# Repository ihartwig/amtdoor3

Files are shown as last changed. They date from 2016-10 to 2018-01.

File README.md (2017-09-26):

AMT Door 3
==========

This repository houses hardware for the 3rd generation smart lock at Ace Monster Toys in Berkeley, CA. The hardware and software in this repo plus the PoEPi Hat make a single-cable solution for network connected locks.

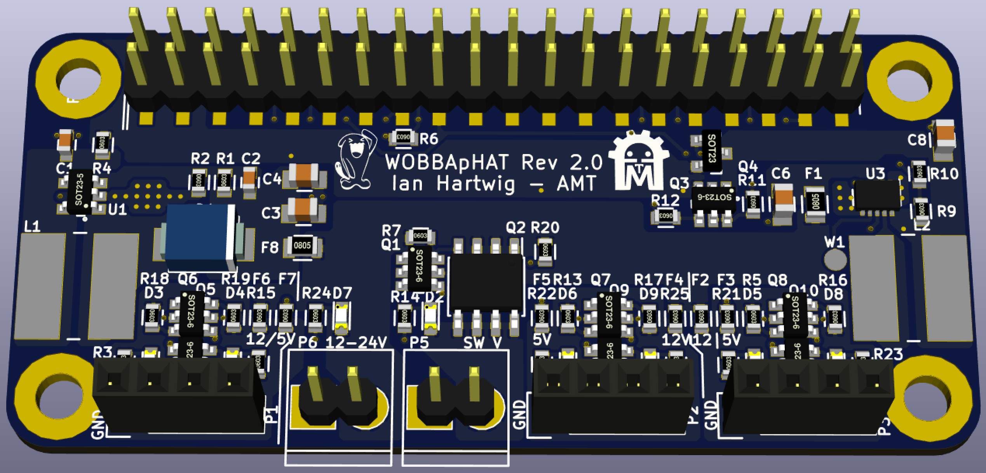
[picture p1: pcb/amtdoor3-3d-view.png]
AMT Door 3 Breakout 3D render


## Features

* Wide Operation Buck Boost and Automation pHat (WOBBApHAT)
  * RPi Zero-sized pHAT
  * bi-directional level shifting for RFID Reader I/O (UART), PWM, and switch inputs (GPIO)
  * 12-24V strike power from on-board boost or aux input
  * (optionally) 5V RPi power from 12-24V source
  * order at http://dirtypcbs.com/store/designer/details/9832/5763/wobbaphat-for-amtdoor3

## Development Structure

* **docs**: Documentation used in designs.
* **pcb**: WOBBApHAT board to connect RPi Zero with RFID Reader and door strike.

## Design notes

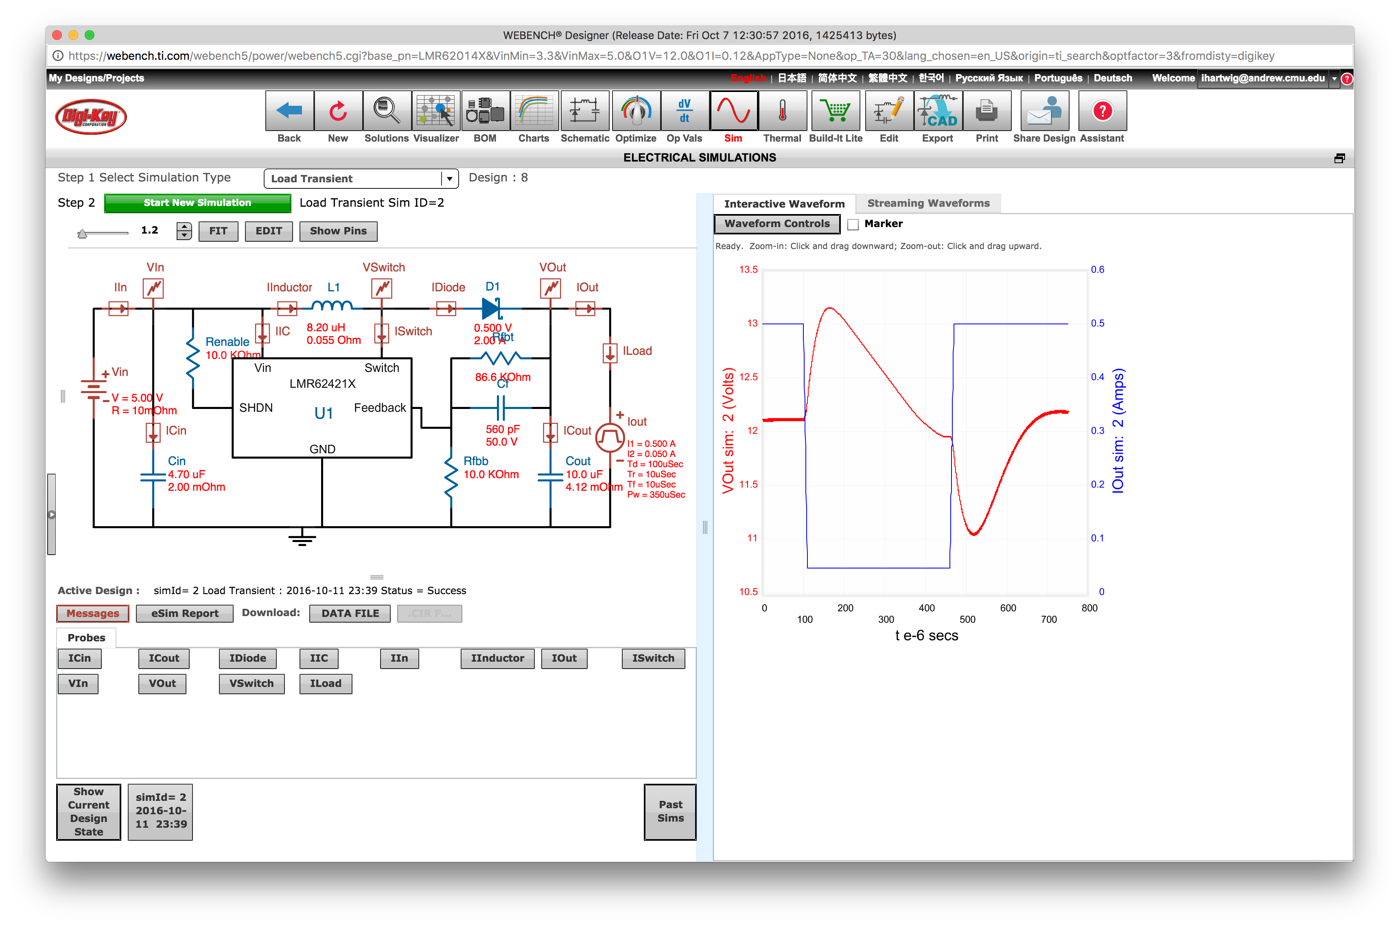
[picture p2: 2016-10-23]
docs/Screen Shot 2016-10-11 at 11.40.16 PM.png

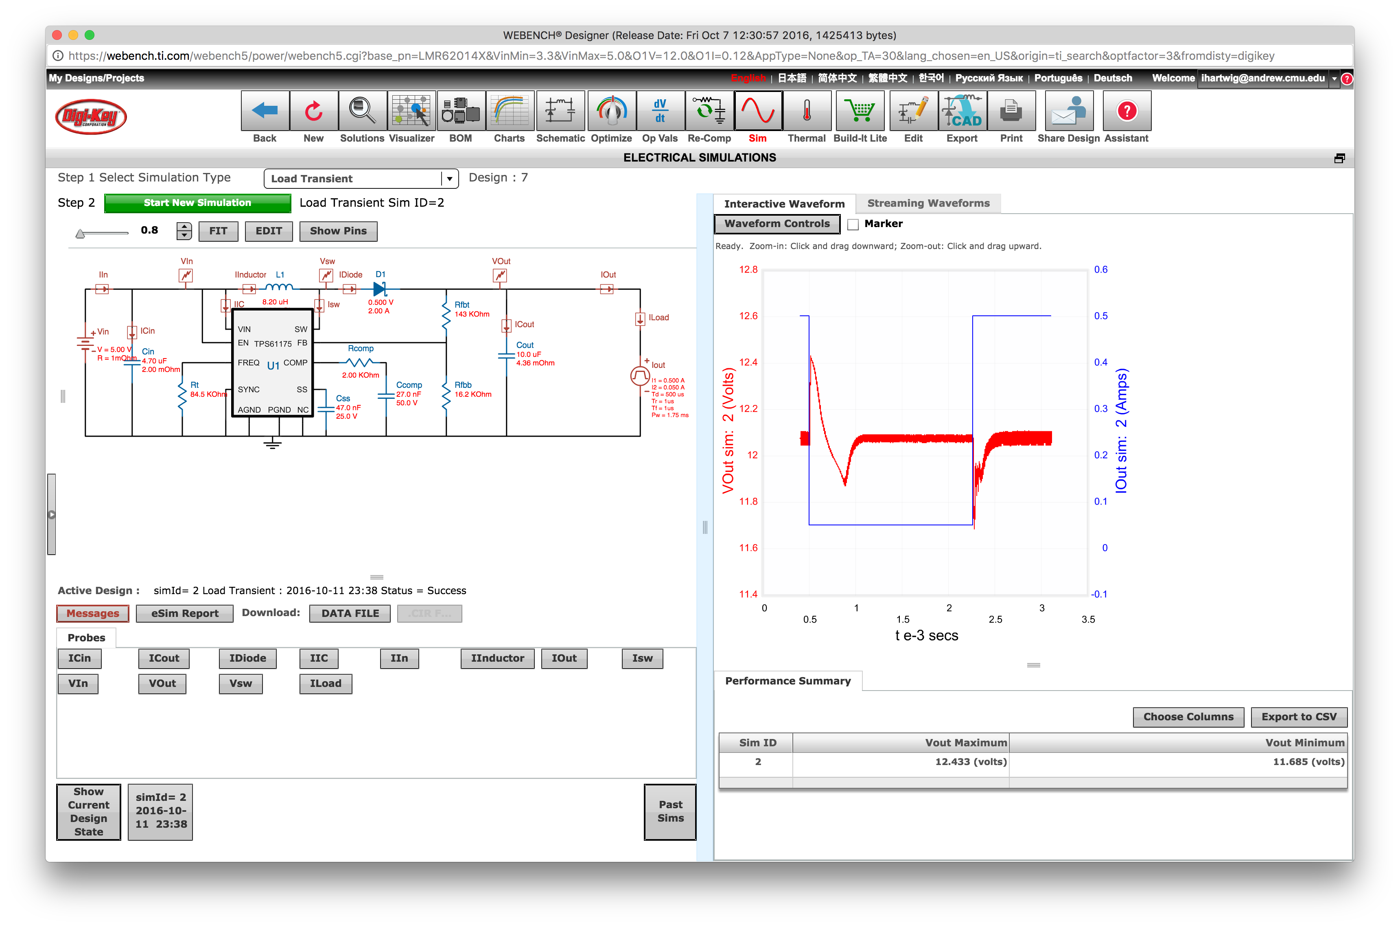
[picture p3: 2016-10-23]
docs/Screen Shot 2016-10-11 at 11.38.27 PM.png

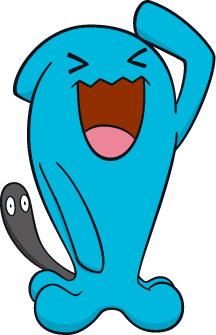
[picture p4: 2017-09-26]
pcb/wobbuffet.png

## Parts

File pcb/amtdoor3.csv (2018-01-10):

Component | Description | Part | References | Value | Footprint | Quantity Per PCB | Datasheet | Type | Digikey Part No | Mfg | Mfg Part No | Pop | Alt Mfg | Alt Mfg Part No
1 | Unpolarized capacitor | C_Small | C2 | 15pF | C_0603 | 1 |  | SMT
2 | Unpolarized capacitor | C_Small | C1 | 1uF | C_0603 | 1 |  | SMT
3 | Unpolarized capacitor | C_Small | C3 C4 C6 | 2.2uF 50V | C_0805 | 3 |  | SMT
4 | Unpolarized capacitor | C_Small | C8 | 22uF 10V | C_0805 | 1 |  | SMT
5 | Schottky diode, small symbol | D_Schottky_Small | D1 | 15V 1A | SMB_Standard | 1 |  | SMT | VS-10BQ015-M3/5BTGICT-ND | Vishay Semiconductor | VS-10BQ015-M3/5BT
6 |  | Led_Small | D2 D3 D4 D5 D6 D7 D8 D9 | LED Green | LED_0603 | 8 |  | SMT | 160-1183-1-ND | Lite-On | LTST-C190GKT
7 |  | F_Small | F1 | 250mA | R_0805 | 1 |  |  |  |  |  | DNP
8 |  | F_Small | F8 | 500mA | R_0805 | 1 |  |  |  |  |  | DNP
9 |  | F_Small | F2 F3 F4 F5 F6 F7 | F_Small | R_0603 | 6 |  |  |  |  |  | DNP
10 |  | AMT-LOGO | G3 | AMT-LOGO | amt-logo-fcu | 1
11 |  | AMT-LOGO | G4 | AMT-LOGO | amt-logo-fsilk-lg | 1
12 |  | WOBBAPHAT-LOGO | G1 | WOBBAPHAT-LOGO | wobbaphat-logo-fcu | 1
13 |  | WOBBAPHAT-LOGO | G2 | WOBBAPHAT-LOGO | wobbaphat-logo-fsilk-lg | 1
14 |  | hole-metalized-no4 | H1 H2 H3 H4 | hole-metalized-no4 | hole-m3 | 4 |  | nostuff
15 |  | INDUCTOR_SMALL | L2 | 10uH | Choke_SMD_Wuerth-WE-PD2-Typ-L | 1 |  | SMT | 587-2081-1-ND | Taiyo Yuden | NR6045T100M
16 |  | INDUCTOR_SMALL | L1 | 4.7uH | Choke_SMD_Wuerth-WE-PD2-Typ-L | 1 |  | SMT | 587-2100-1-ND | Taiyo Yuden | NR6028T4R7M
17 |  | CONN_01X02 | P5 P6 | CONN_01X02 | Pin_Header_Straight_1x02_Pitch3.5mm | 2 |  | TH | ED2740-ND | On Shore Technology, Inc. | OSTTE020104
18 |  | CONN_01X04 | P1 P2 P3 | CONN_01X04 | Socket_Strip_Straight_1x04 | 3 |  | TH
19 |  | CONN_02X20 | P4 | dnp-REF-182665-01 | Pin_Header_Straight_TH-SMT-NoPaste_2x20 | 1 |  |  |  |  |  | DNP
20 |  | DMMT3906_Dual_PNP | Q3 | DMMT3906_Dual_PNP | SOT-23-6 | 1 |  | SMT | DMMT3906-7-FDICT-ND | Diodes Inc | DMMT3906-7-F
21 | Transistor Dual N-MOSFET (DMN63D8LDW, 2N7002DW) | Q_NMOS_DUAL | Q1 Q5 Q6 Q7 Q8 Q9 Q10 | Q_NMOS_DUAL | SOT-23-6 | 7 |  | SMT | DMN5L06DMKDICT-ND | Diodes Inc | DMN5L06DMK-7
22 | Transistor P-MOSFET with substrate diode (general) | Q_PMOS_GSD | Q4 | Q_PMOS_GSD | SOT-23 | 1 |  | SMT | DMP3099L-7DICT-ND | Diodes Inc | DMP3099L-7
23 | Transistor P-MOSFET High Power (IRF9393, DMP3056) | Q_PMOS_HP | Q2 | Q_PMOS_HP | SOIC-8_3.9x4.9mm_Pitch1.27mm | 1 |  | SMT | DMG4435SSS-13DICT-ND | Diodes Inc | DMG4435SSS-13 |  | Diodes Inc | DMP3085LSS-13
24 | Resistor, small symbol | R_Small | R4 | 0 | R_0603 | 1 |  |  |  |  |  | DNP
25 | Resistor, small symbol | R_Small | R5 R6 R7 R11 R13 R16 R17 R18 R19 R20 | 10k | R_0603 | 10 |  | SMT
26 | Resistor, small symbol | R_Small | R10 | 150k | R_0603 | 1 |  | SMT
27 | Resistor, small symbol | R_Small | R3 R15 R21 R22 R23 R25 | 1k | R_0603 | 6 |  | SMT
28 | Resistor, small symbol | R_Small | R14 R24 | 2.2k | R_0603 | 2 |  | SMT
29 | Resistor, small symbol | R_Small | R1 | 432k | R_0603 | 1 |  | SMT
30 | Resistor, small symbol | R_Small | R12 | 47k | R_0603 | 1 |  | SMT
31 | Resistor, small symbol | R_Small | R2 | 49.9k | R_0603 | 1 |  | SMT
32 | Resistor, small symbol | R_Small | R9 | 787k | R_0603 | 1 |  | SMT
33 | Boost Switching Regulator IC Positive Adjustable 2.5V 1 Output 1.4A | SC4503-TSOT-23 | U1 | SC4503-TSOT-23 | SOT-23-5 | 1 |  | SMT | SC4503TSKCT-ND | Semtech Corporation | SC4503TSKTRT |  | Texas Instruments | LMR62421XMF/NOPB
34 | 28-V, 0.5-A Step-Down Converter With Sleep Mode | TPS62177 | U3 | TPS62175 | DFN-10-1EP_2x3mm_Pitch0.5mm | 1 |  | SMT | 296-39451-1-ND | Texas Instruments | TPS62175DQCR
35 | point | TEST_1P | W1 | TEST_1P | Measurement_Point_Round-SMD-Pad_Small | 1
Component Groups: | 35
Component Count: | 76
Fitted Components: | 76
Number of PCBs: | 1
Total components: | 76
Schematic Version: | 2.0
Schematic Date: | 2017-09-25
BoM Date: | Thursday, January 04, 2018 'PMt' 11:07:57 PM
Schematic Source: | /Users/ihartwig/repos/amtdoor3/pcb/amtdoor3.sch
KiCad Version: | Eeschema 4.0.7

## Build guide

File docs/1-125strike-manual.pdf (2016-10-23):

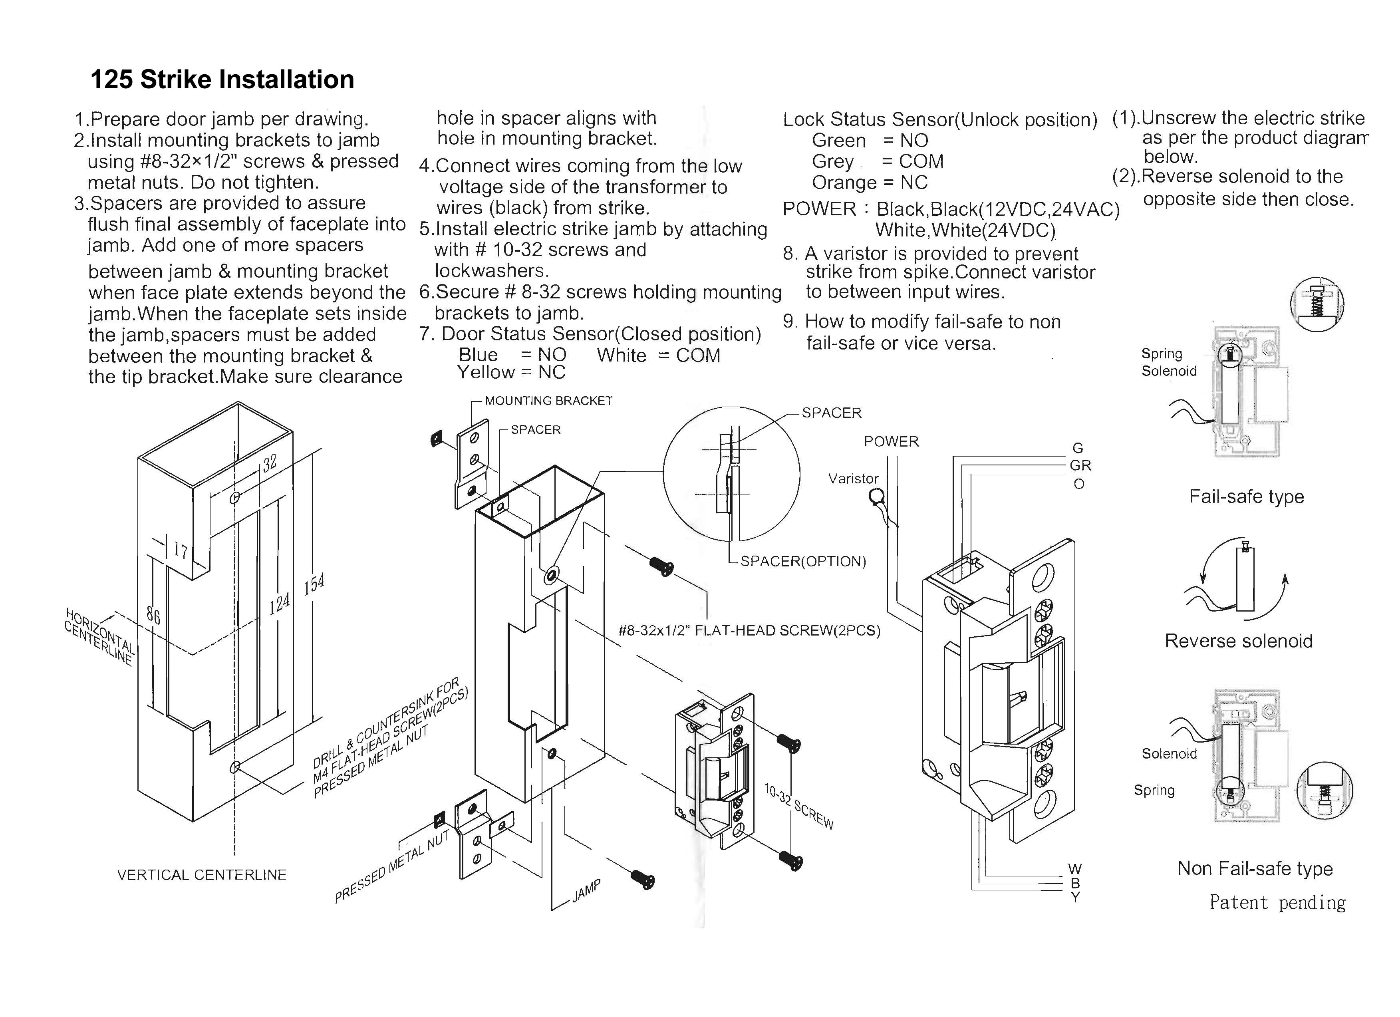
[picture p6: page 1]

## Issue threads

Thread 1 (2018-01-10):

GPIO indicator LEDs are flipped

ihartwig, 2018-01-10:
GPIO indicator LEDs are next to their pair's pin instead of their own because the dual FET package have G and S on the same side.

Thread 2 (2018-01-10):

24V signals are only safe to 20V

ihartwig, 2018-01-10:
All the 24V signals touch the gate of a dual FET somewhere, and it looks like those parts only come with a Vgs max of +-20V. Add resistors or find a dual FET that doesn't seem to exist.

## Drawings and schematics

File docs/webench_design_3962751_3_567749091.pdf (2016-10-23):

## WEBENCH ® Design Report

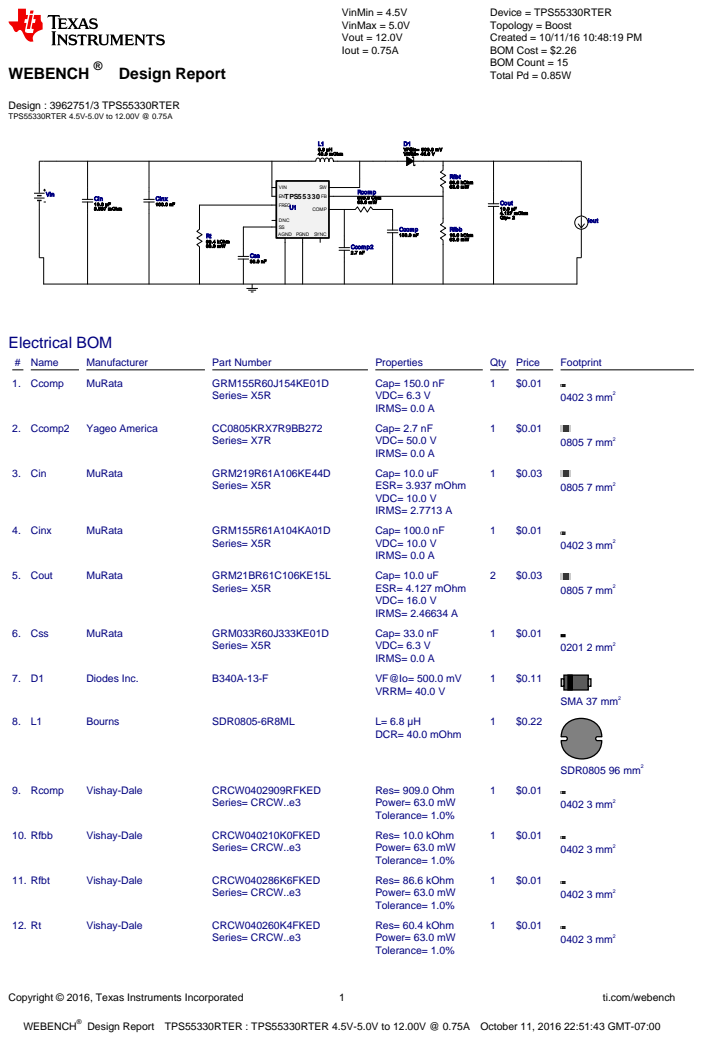
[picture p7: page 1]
Copyright © 2016, Texas Instruments Incorporated; ti.com/webench; WEBENCH®; Design : 3962751/3 TPS55330RTER TPS55330RTER 4.5V-5.0V to 12.00V @ 0.75A; VinMin = 4.5V VinMax = 5.0V Vout = 12.0V Iout = 0.75A; Device = TPS55330RTER Topology = Boost Created = 10/11/16 10:48:19 PM BOM Cost = $2.26 BOM Count = 15 Total Pd = 0.85W; Ccomp 150.0 nF; Ccomp2 2.7 nF; Cin 10.0 µF 3.937 mOhm; Cinx; Cout 10.0 µF; 4.127 mOhm Qty= 2; Css 33.0 nF; D1 VF@Io= 500.0 mV VRRM= 40.0 V; L1 6.8 µH 40.0 mOhm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

Design Report TPS55330RTER : TPS55330RTER 4.5V-5.0V to 12.00V @ 0.75A October 11, 2016 22:51:43 GMT-07:00

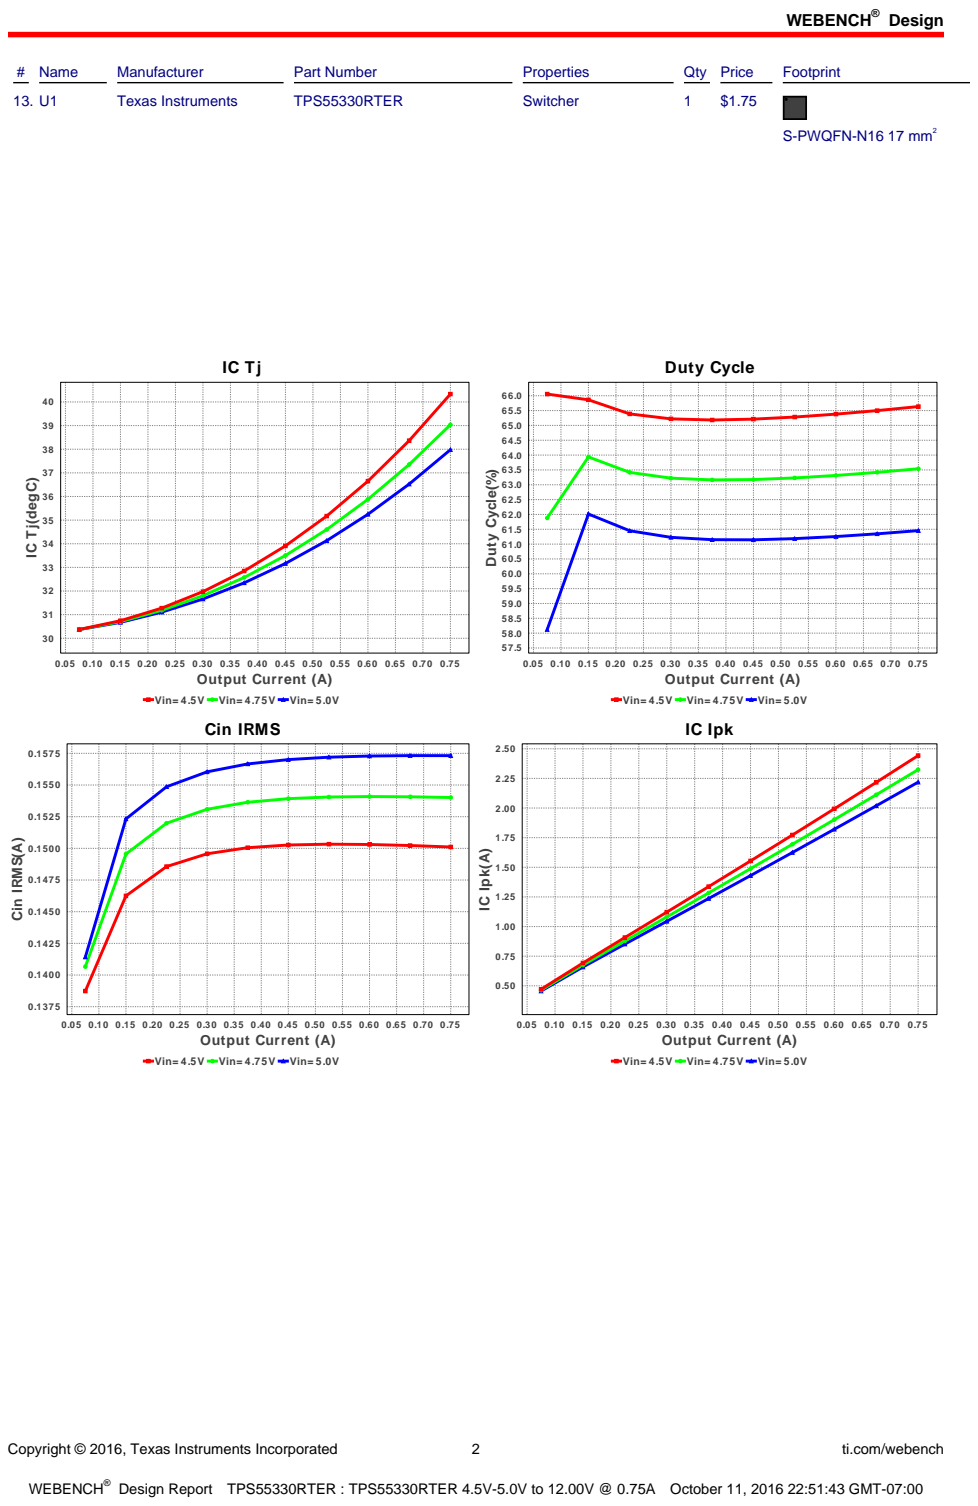
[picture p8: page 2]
Design; Copyright © 2016, Texas Instruments Incorporated; ti.com/webench; # Name; Manufacturer; Part Number; Properties; Qty Price; Footprint; Texas Instruments; TPS55330RTER; Switcher; S-PWQFN-N16 17 mm²; 0.05 0.10 0.15 0.20 0.25 0.30 0.35 0.40 0.45 0.50 0.55 0.60 0.65 0.70 0.75 Output Current (A); Duty Cycle; Duty Cycle(%); Cin IRMS(A); IC Ipk; IC Ipk(A)

IC Tj(degC)

Vin= 4.5V Vin= 4.75V Vin= 5.0V
Cin IRMS

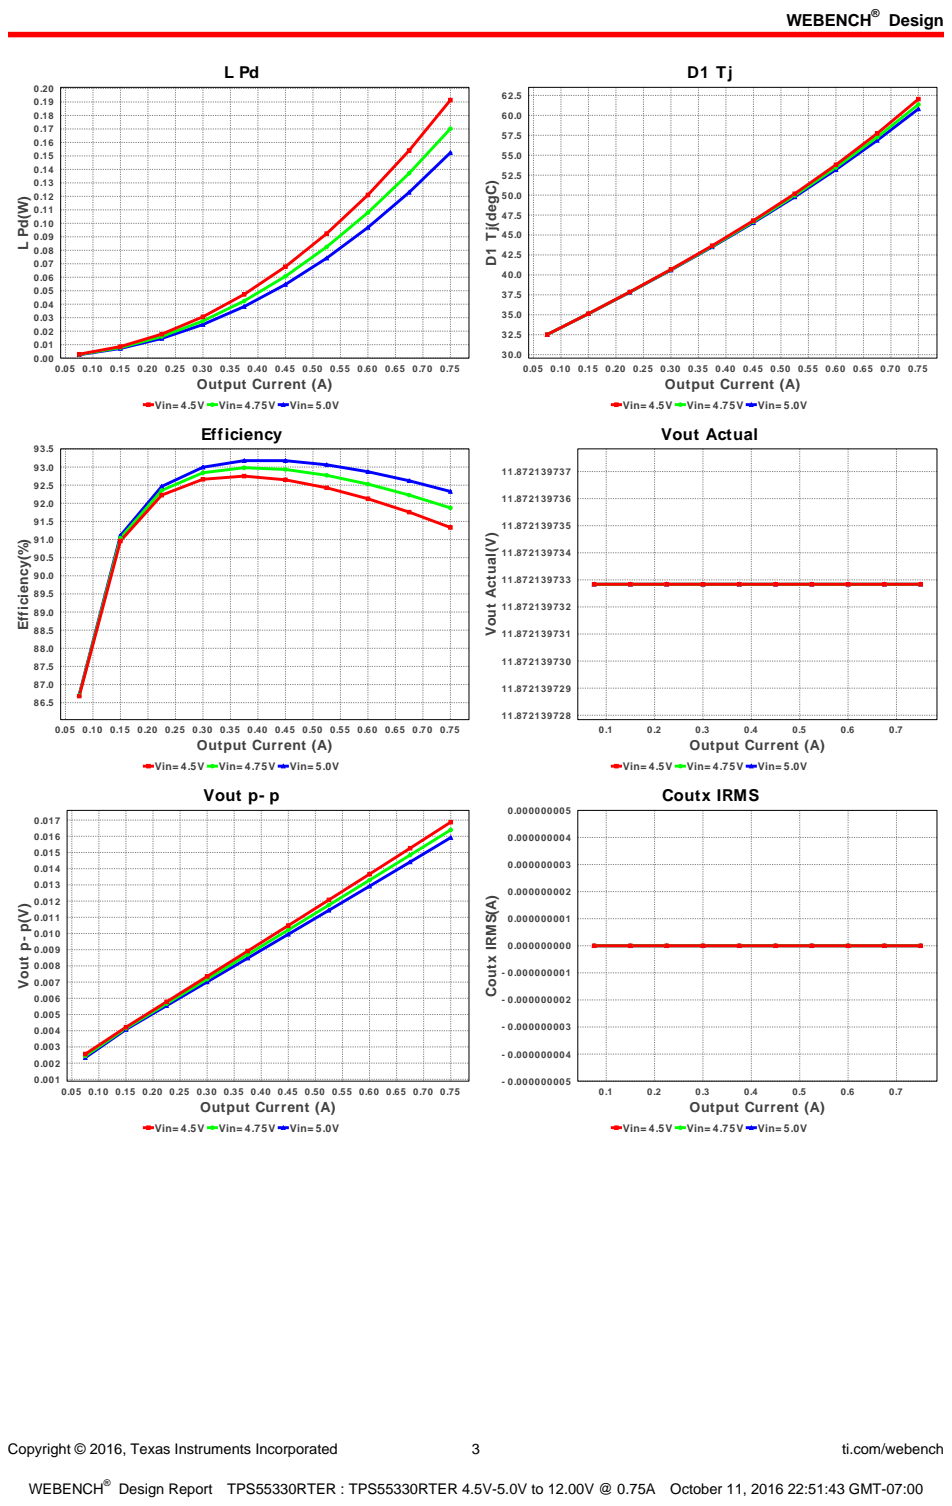
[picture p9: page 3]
Copyright © 2016, Texas Instruments Incorporated; ti.com/webench; 0.05 0.10 0.15 0.20 0.25 0.30 0.35 0.40 0.45 0.50 0.55 0.60 0.65 0.70 0.75 Output Current (A); D1 Tj(degC); Efficiency(%); 0.7 Output Current (A); Vout Actual(V); Vout p- p(V); Coutx IRMS(A)

Vin= 4.5V Vin= 4.75V Vin= 5.0V
Efficiency

Vout Actual

Vout p- p

Coutx IRMS

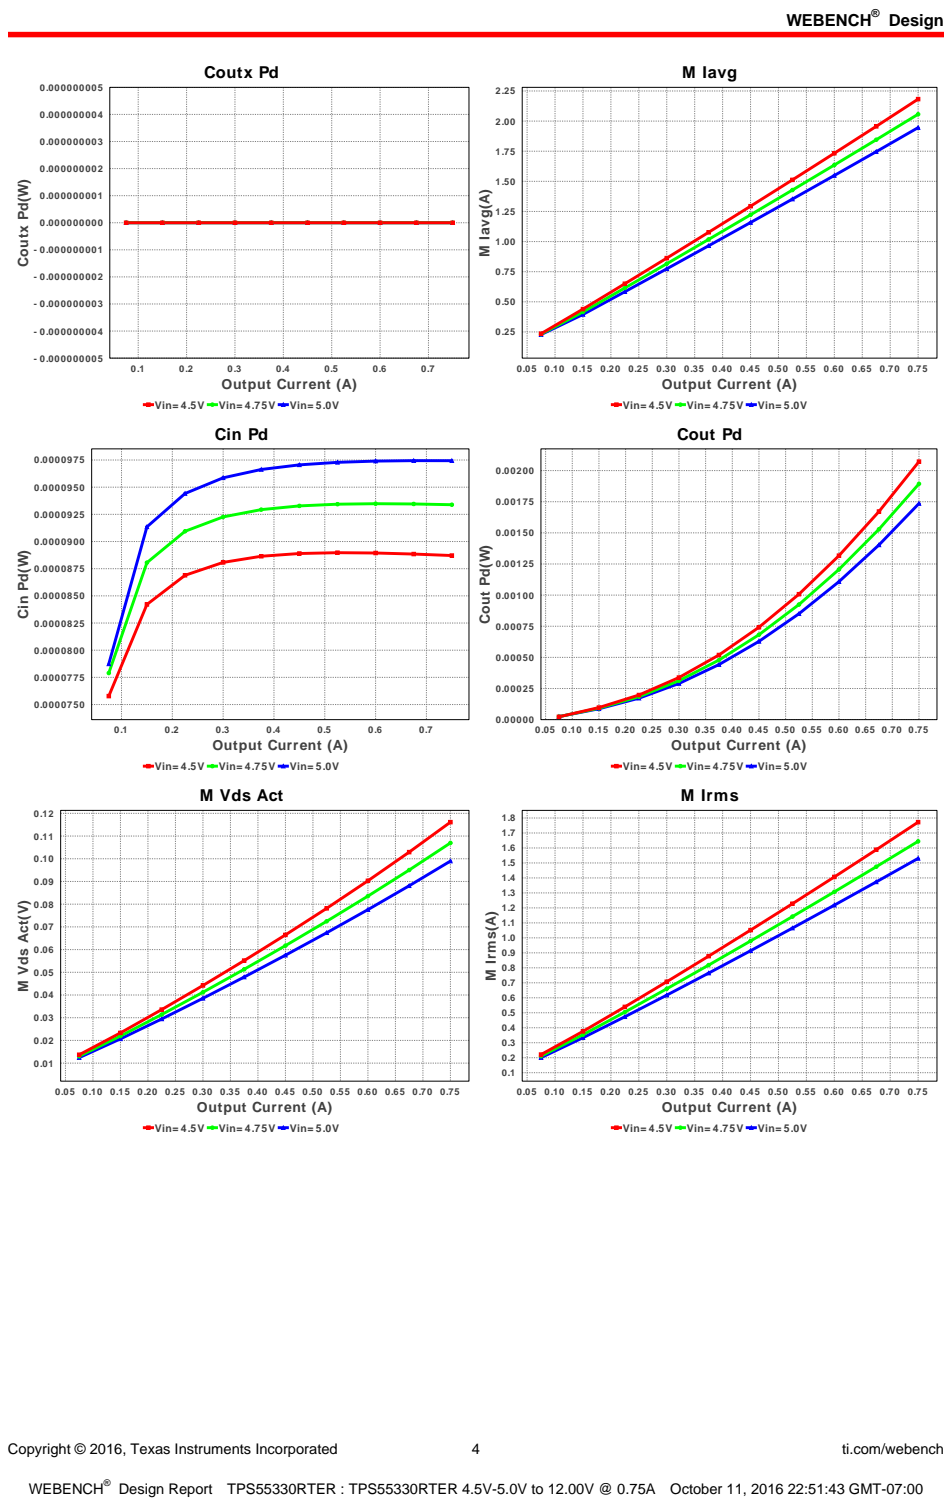
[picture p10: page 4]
Copyright © 2016, Texas Instruments Incorporated; ti.com/webench; Coutx Pd; 0.7 Output Current (A); Coutx Pd(W); M Iavg; 0.05 0.10 0.15 0.20 0.25 0.30 0.35 0.40 0.45 0.50 0.55 0.60 0.65 0.70 0.75 Output Current (A); M Iavg(A); Cin Pd; Cin Pd(W); Cout Pd(W); M Vds Act(V); M Irms; M Irms(A)

Vin= 4.5V Vin= 4.75V Vin= 5.0V

Cout Pd

M Vds Act

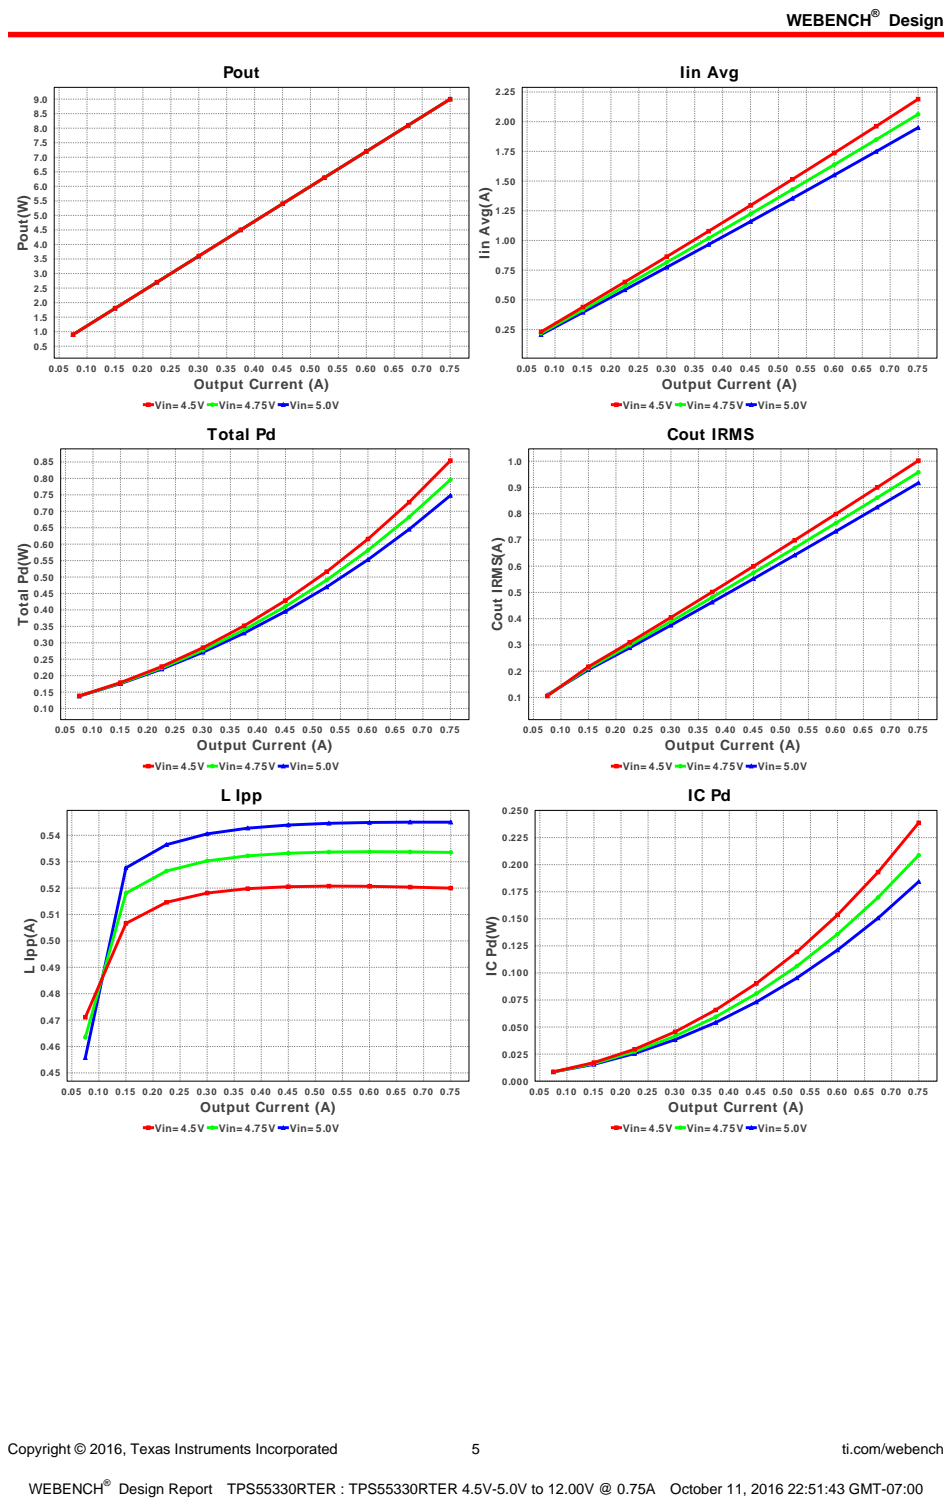
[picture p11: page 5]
Copyright © 2016, Texas Instruments Incorporated; ti.com/webench; Pout; 0.05 0.10 0.15 0.20 0.25 0.30 0.35 0.40 0.45 0.50 0.55 0.60 0.65 0.70 0.75 Output Current (A); Pout(W); Iin Avg; Iin Avg(A); Total Pd(W); Cout IRMS(A); L Ipp; L Ipp(A)

Vin= 4.5V Vin= 4.75V Vin= 5.0V
Total Pd

Cout IRMS

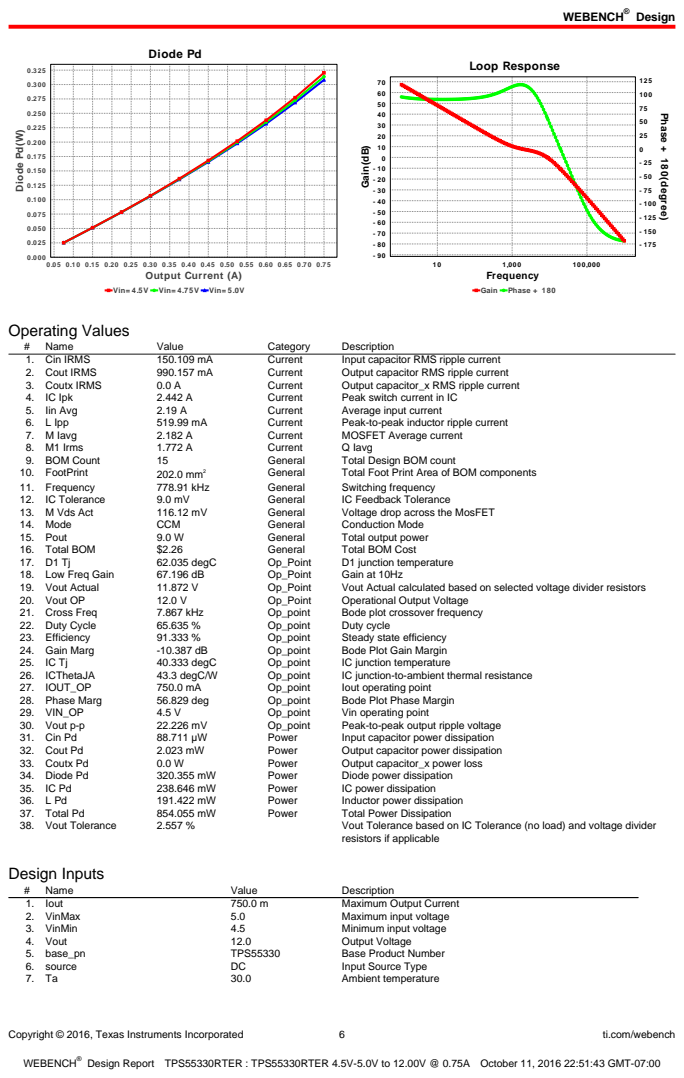
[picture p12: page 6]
Copyright © 2016, Texas Instruments Incorporated; ti.com/webench; Diode Pd; 0.05 0.10 0.15 0.20 0.25 0.30 0.35 0.40 0.45 0.50 0.55 0.60 0.65 0.70 0.75 Output Current (A); Diode Pd(W); Loop Response; Gain Phase + 180; 100,000 Frequency; Gain(dB); Phase + 180(degree); Operating Values; Name; Value; Category; Description; 1. Cin IRMS; Current; Input capacitor RMS ripple current; 2. Cout IRMS; Output capacitor RMS ripple current; 3. Coutx IRMS; Output capacitor_x RMS ripple current; 4. IC Ipk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

Vin= 4.5V Vin= 4.75V Vin= 5.0V

resistors if applicable

Copyright © 2016, Texas Instruments Incorporated | 7 | ti.com/webench

## Design Assistance

1. TPS55330 Product Folder : http://www.ti.com/product/TPS55330 : contains the data sheet and other resources.

Texas Instruments' WEBENCH simulation tools attempt to recreate the performance of a substantially equivalent physical implementation
of the design. Simulations are created using Texas Instruments' published specifications as well as the published specifications of other device manufacturers. While Texas Instruments does update this information periodically, this information may not be current at the time the simulation is built. Texas Instruments does not warrant the accuracy or completeness of the specifications or any information contained therein. Texas Instruments does not warrant that any designs or recommended parts will meet the specifications you entered, will be suitable for your application or fit for any particular purpose, or will operate as shown in the simulation in a physical implementation. Texas Instruments does not warrant that the designs are production worthy.
You should completely validate and test your design implementation to confirm the system functionality for your application prior to production.
Use of Texas Instruments' WEBENCH simulation tools is subject to Texas Instruments' Site Terms and Conditions of Use. (http://www.ti.com/corp/docs/legal/termsofuse.shtml) Prototype boards based on WEBENCH created designs are provided AS IS without warranty of any kind for evaluation and testing purposes and are subject to the terms of the Evaluation License Agreement. (http://www.ti.com/corp/docs/legal/termsofuse_estore.shtml)

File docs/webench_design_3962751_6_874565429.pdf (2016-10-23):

## WEBENCH ® Design Report

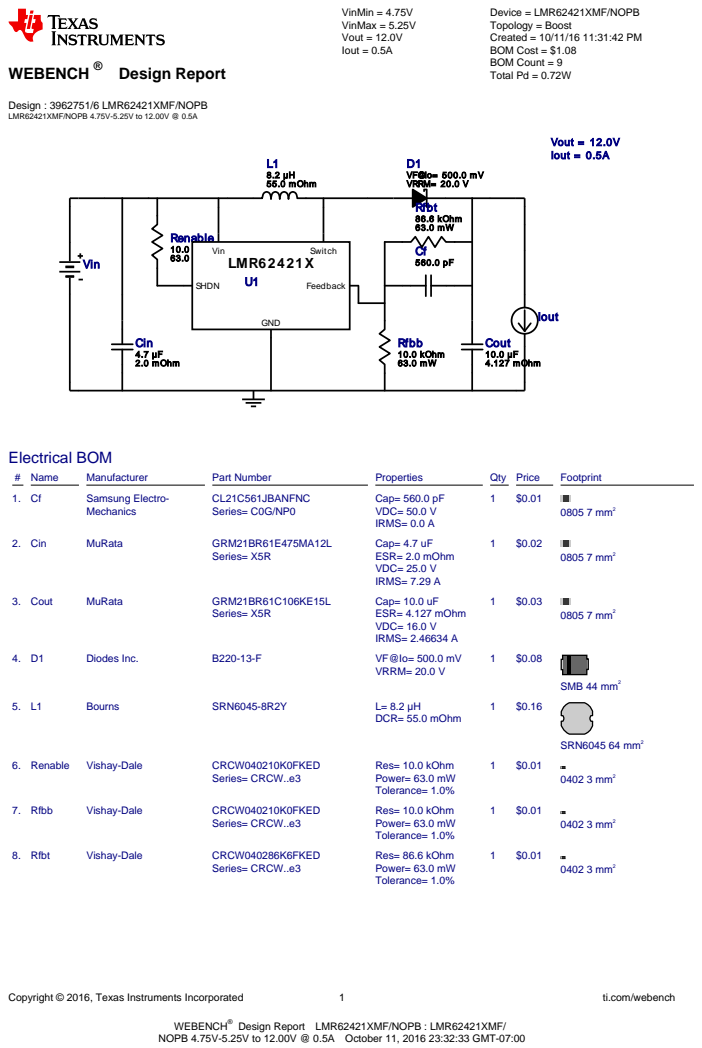
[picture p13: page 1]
Copyright © 2016, Texas Instruments Incorporated; ti.com/webench; Design : 3962751/6 LMR62421XMF/NOPB LMR62421XMF/NOPB 4.75V-5.25V to 12.00V @ 0.5A; VinMin = 4.75V VinMax = 5.25V Vout = 12.0V Iout = 0.5A; Device = LMR62421XMF/NOPB Topology = Boost Created = 10/11/16 11:31:42 PM BOM Cost = $1.08 BOM Count = 9 Total Pd = 0.72W; Cin 4.7 µF 2.0 mOhm; Cout 10.0 µF 4.127 mOhm; D1 VF@Io= 500.0 mV VRRM= 20.0 V; L1 8.2 µH 55.0 mOhm; Renable 10.0 kOhm 63.0 mW; Rfbb 10.0 kOhm 63.0 mW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

WEBENCH®
NOPB 4.75V-5.25V to 12.00V @ 0.5A October 11, 2016 23:32:33 GMT-07:00

Design Report LMR62421XMF/NOPB : LMR62421XMF/

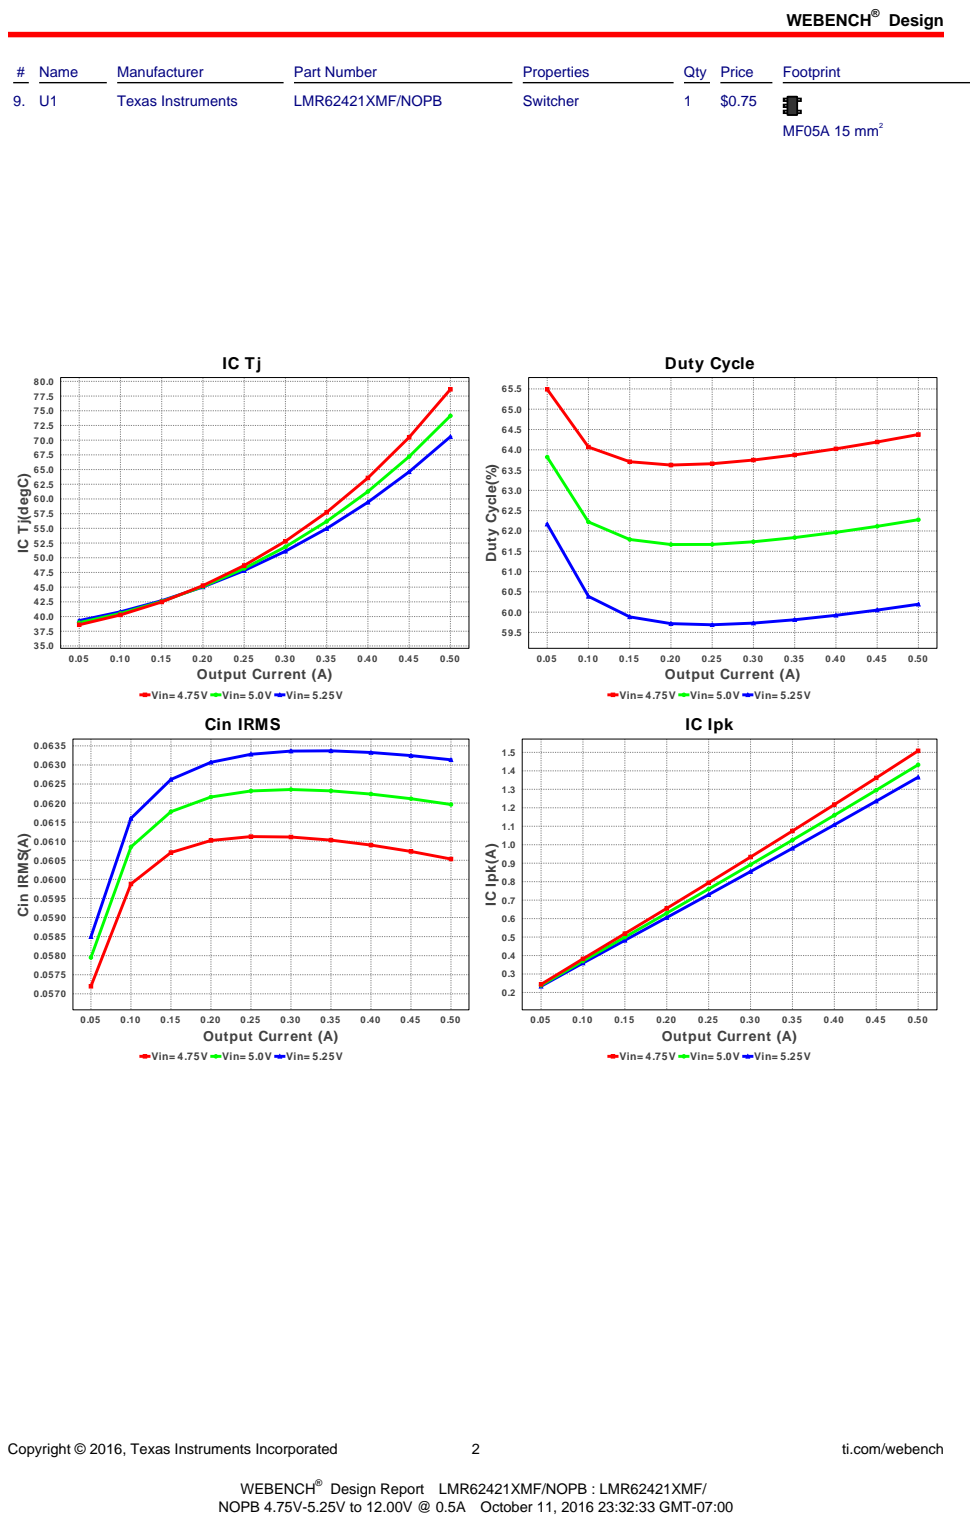
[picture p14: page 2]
Design; Copyright © 2016, Texas Instruments Incorporated; ti.com/webench; # Name; Manufacturer; Part Number; Properties; Qty Price; Footprint; Texas Instruments; LMR62421XMF/NOPB; Switcher; MF05A 15 mm²; 0.50 Output Current (A); Duty Cycle; Duty Cycle(%); Cin IRMS(A); IC Ipk; IC Ipk(A)

IC Tj(degC)

Vin= 4.75V Vin= 5.0V Vin= 5.25V
Cin IRMS

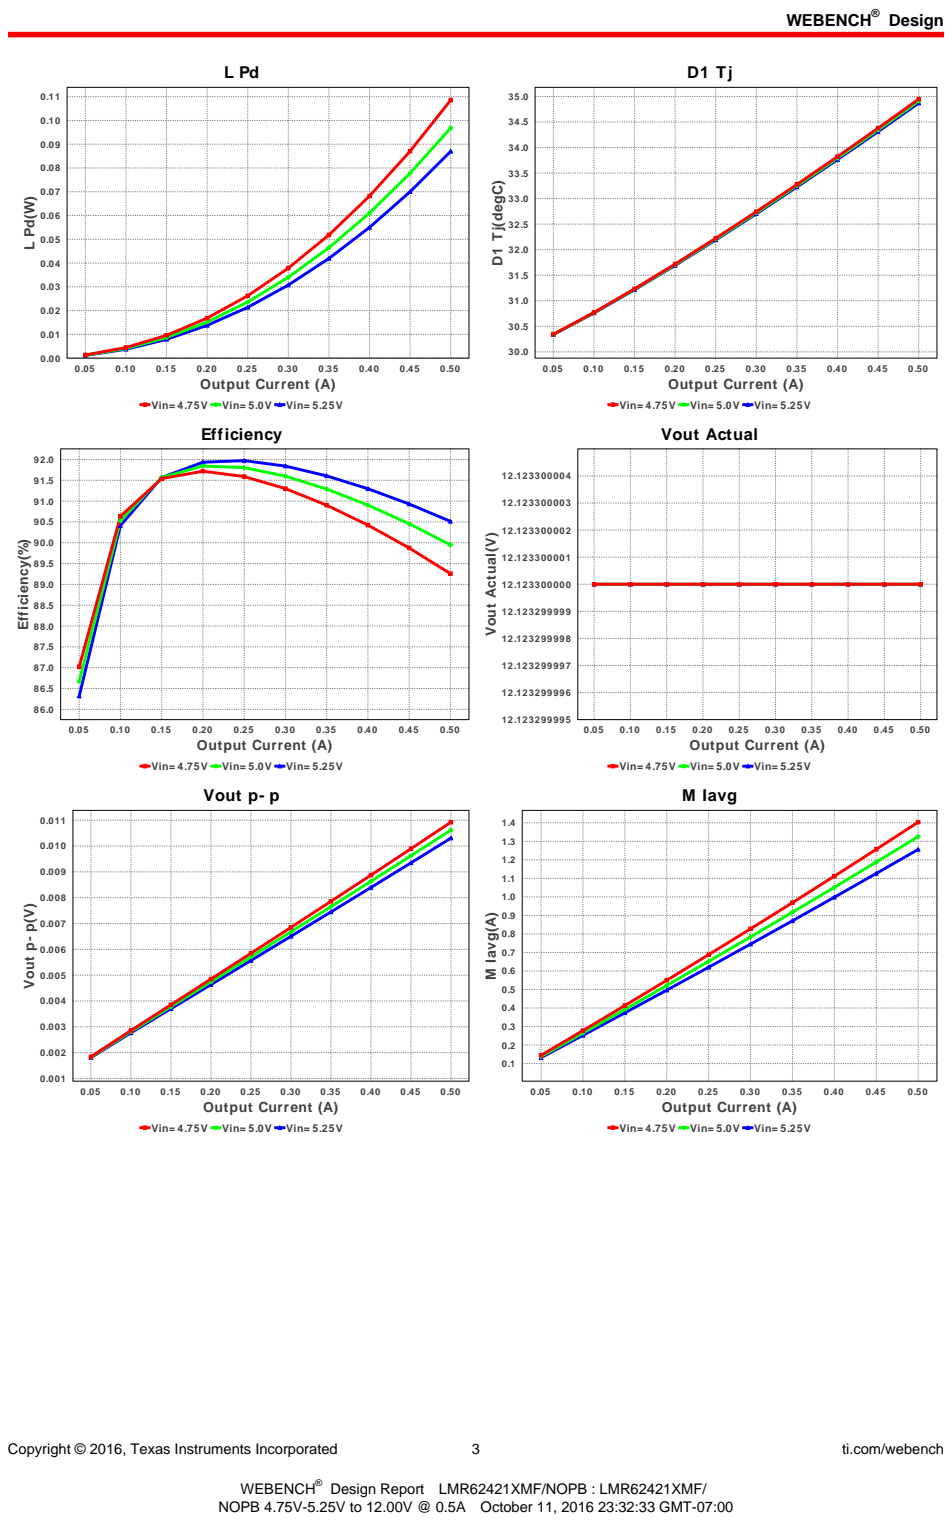
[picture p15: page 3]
Copyright © 2016, Texas Instruments Incorporated; ti.com/webench; 0.50 Output Current (A); D1 Tj(degC); Efficiency(%); Vout Actual(V); Vout p- p(V); M Iavg; M Iavg(A)

Vin= 4.75V Vin= 5.0V Vin= 5.25V
Efficiency

Vout Actual

Vout p- p

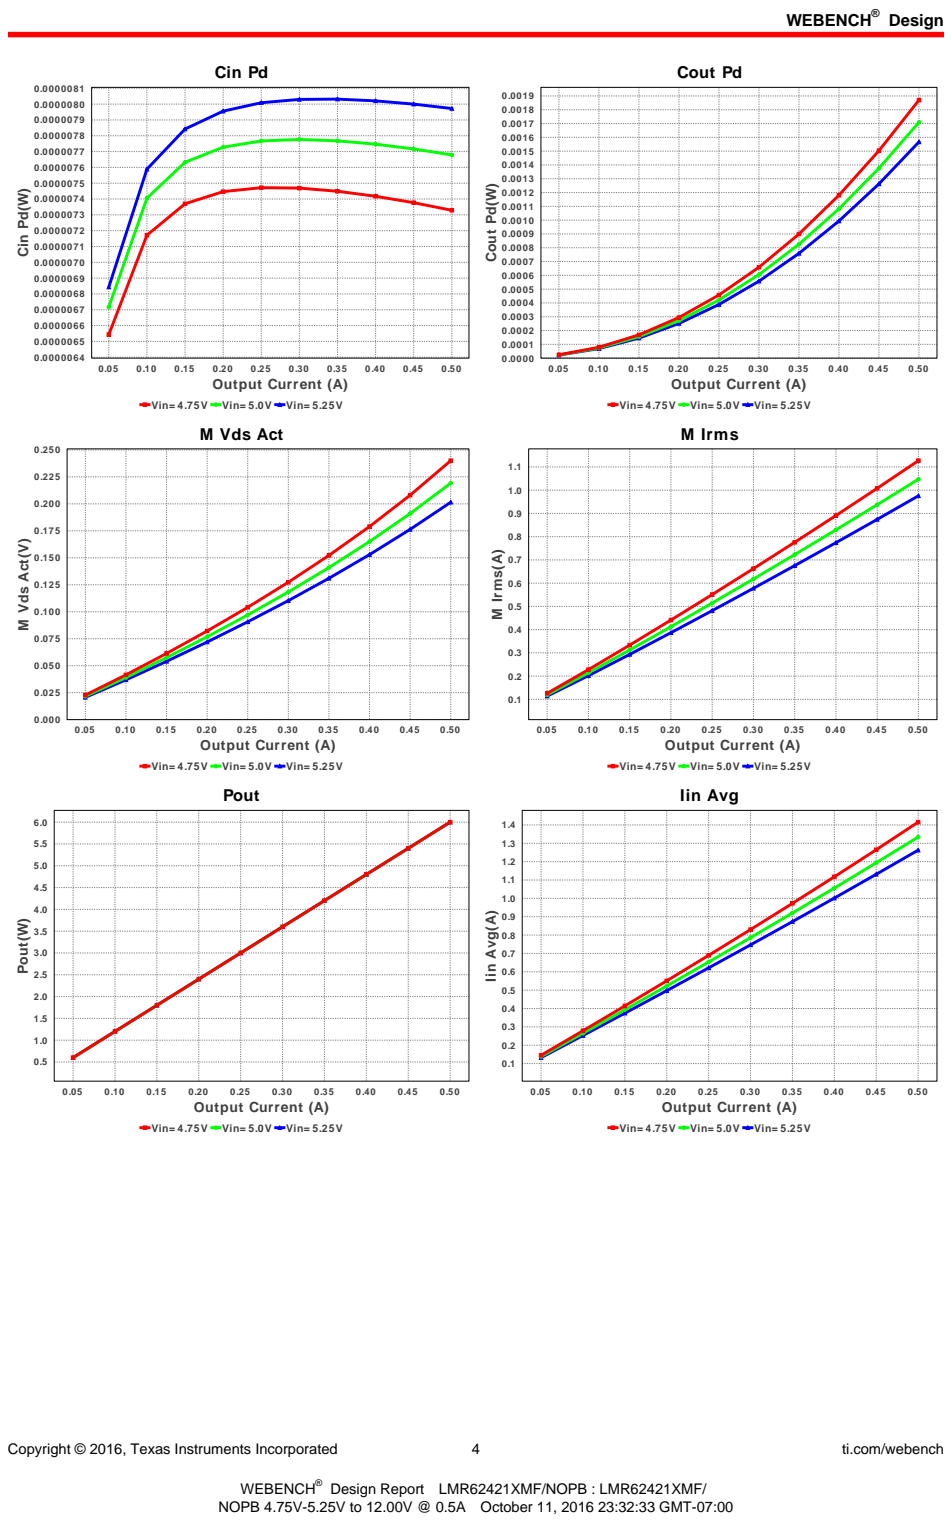
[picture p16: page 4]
Copyright © 2016, Texas Instruments Incorporated; ti.com/webench; Cin Pd; 0.50 Output Current (A); Cin Pd(W); Cout Pd; Cout Pd(W); M Vds Act(V); M Irms; M Irms(A); Pout; Pout(W); Iin Avg; Iin Avg(A)

Vin= 4.75V Vin= 5.0V Vin= 5.25V
M Vds Act

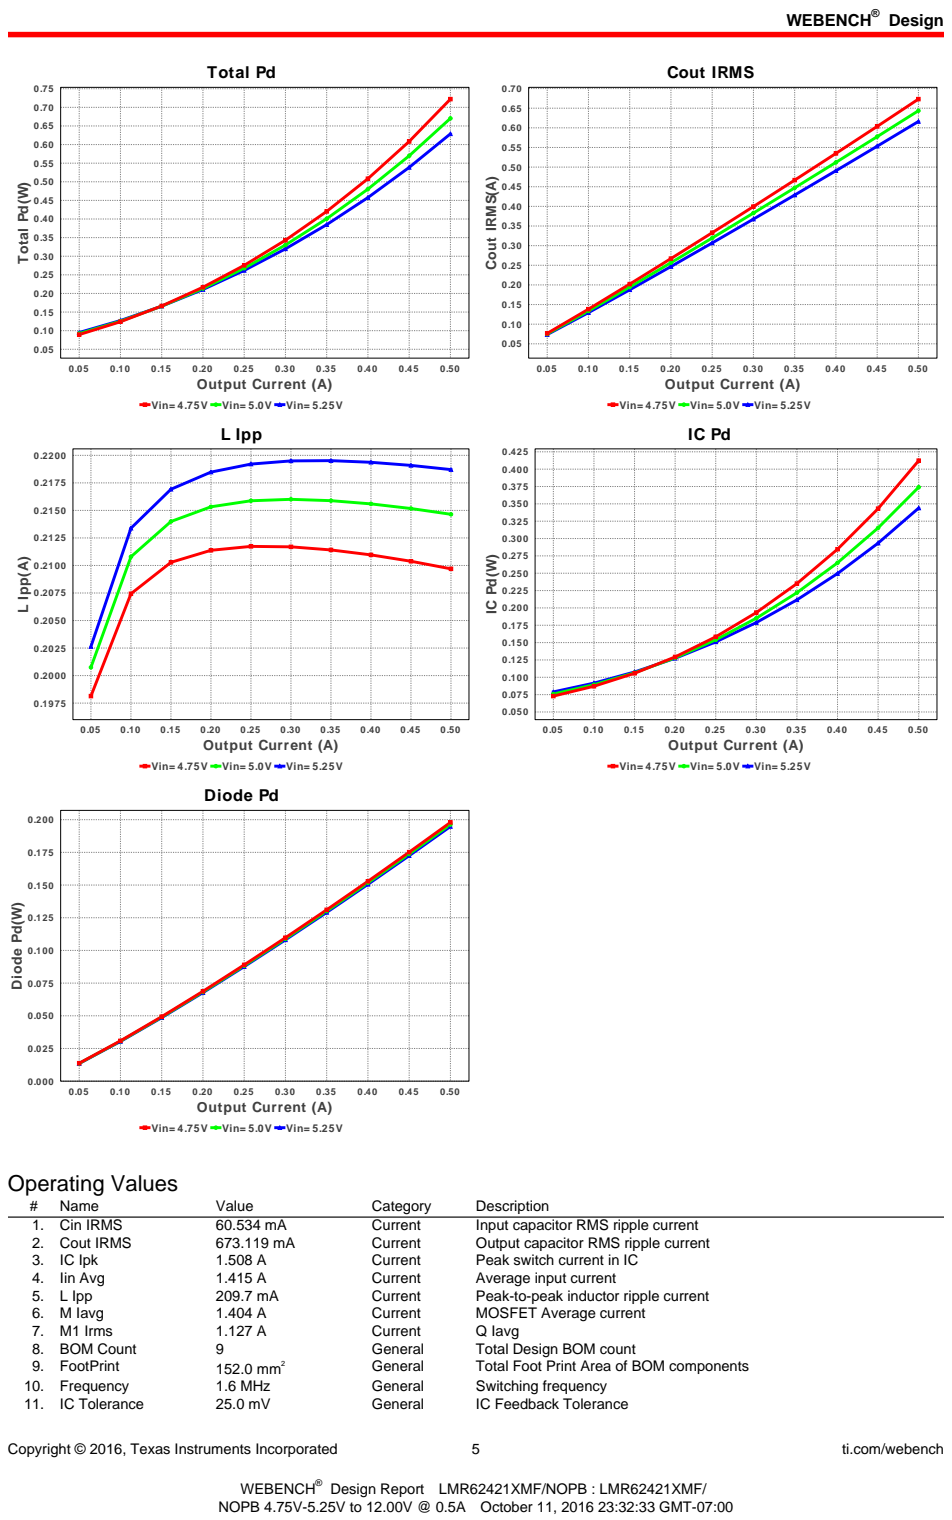
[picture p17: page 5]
Copyright © 2016, Texas Instruments Incorporated; ti.com/webench; Total Pd; 0.50 Output Current (A); Total Pd(W); Cout IRMS; Cout IRMS(A); L Ipp; L Ipp(A); Diode Pd(W); Operating Values; Name; Value; Category; Description; 1. Cin IRMS; Current; Input capacitor RMS ripple current; 2. Cout IRMS; Output capacitor RMS ripple current; 3. IC Ipk; Peak switch current in IC; 4. Iin Avg; Average input current; 5. L Ipp; Peak-to-peak inductor ripple current; 6. M Iavg; MOSFET Average current; 7. M1 Irms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

Vin= 4.75V Vin= 5.0V Vin= 5.25V

Diode Pd

Copyright © 2016, Texas Instruments Incorporated | 6 | ti.com/webench
# | Name | Value | Category | Description

12. M Vds Act | 240.002 mV | General | Voltage drop across the MosFET
13. Mode | CCM | General | Conduction Mode
14. Pout | 6.0 W | General | Total output power
15. Total BOM | $1.08 | General | Total BOM Cost
16. D1 Tj | 34.947 degC | Op_Point | D1 junction temperature
17. Vout Actual | 12.123 V | Op_Point | Vout Actual calculated based on selected voltage divider resistors
18. Vout OP | 12.0 V | Op_Point | Operational Output Voltage
19. Cross Freq | 8.812 kHz | Op_point | Bode plot crossover frequency
20. Duty Cycle | 64.377 % | Op_point | Duty cycle
21. Efficiency | 89.258 % | Op_point | Steady state efficiency
22. IC Tj | 78.649 degC | Op_point | IC junction temperature
23. ICThetaJA | 118.0 degC/W | Op_point | IC junction-to-ambient thermal resistance
24. IOUT_OP | 500.0 mA | Op_point | Iout operating point
25. Phase Marg | 85.367 deg | Op_point | Bode Plot Phase Margin
26. VIN_OP | 4.75 V | Op_point | Vin operating point
27. Vout p-p | 10.924 mV | Op_point | Peak-to-peak output ripple voltage
28. Cin Pd | 7.329 µW | Power | Input capacitor power dissipation
29. Cout Pd | 1.87 mW | Power | Output capacitor power dissipation
30. Diode Pd | 197.897 mW | Power | Diode power dissipation
31. IC Pd | 412.283 mW | Power | IC power dissipation
32. L Pd | 108.552 mW | Power | Inductor power dissipation
33. Total Pd | 722.099 mW | Power | Total Power Dissipation
34. Vout Tolerance | 3.839 % | Vout Tolerance based on IC Tolerance (no load) and voltage divider
| | | | resistors if applicable

## Design Inputs

# | Name | Value | Description

1. Iout | 500.0 m | Maximum Output Current
2. VinMax | 5.25 | Maximum input voltage
3. VinMin | 4.75 | Minimum input voltage
4. Vout | 12.0 | Output Voltage
5. base_pn | LMR62421X | Base Product Number
6. source | DC | Input Source Type
7. Ta | 30.0 | Ambient temperature

## Design Assistance
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

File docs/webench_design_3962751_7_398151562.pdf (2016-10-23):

## WEBENCH ® Design Report

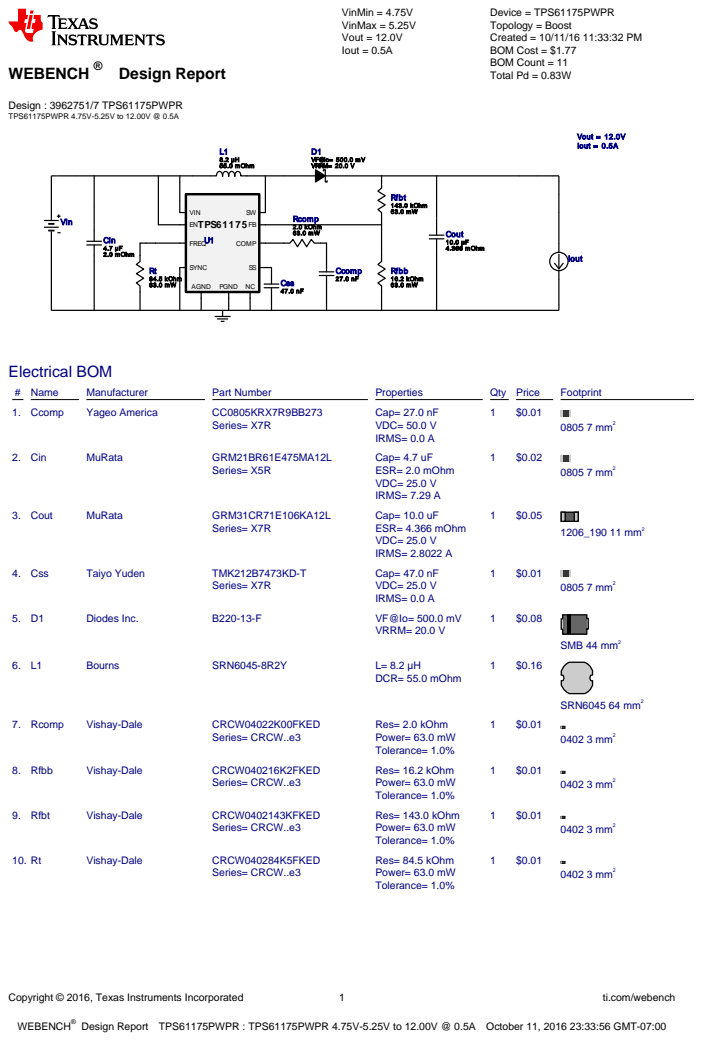
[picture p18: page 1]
Copyright © 2016, Texas Instruments Incorporated; ti.com/webench; WEBENCH®; Design : 3962751/7 TPS61175PWPR TPS61175PWPR 4.75V-5.25V to 12.00V @ 0.5A; VinMin = 4.75V VinMax = 5.25V Vout = 12.0V Iout = 0.5A; Device = TPS61175PWPR Topology = Boost Created = 10/11/16 11:33:32 PM BOM Cost = $1.77 BOM Count = 11 Total Pd = 0.83W; Ccomp 27.0 nF; Cin 4.7 µF 2.0 mOhm; Cout 10.0 µF 4.366 mOhm; Css 47.0 nF; D1 VF@Io= 500.0 mV VRRM= 20.0 V; L1 8.2 µH 55.0 mOhm; Rcomp 2.0 kOhm 63.0 mW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

Design Report TPS61175PWPR : TPS61175PWPR 4.75V-5.25V to 12.00V @ 0.5A October 11, 2016 23:33:56 GMT-07:00

Design; Copyright © 2016, Texas Instruments Incorporated; ti.com/webench; # Name; Manufacturer; Part Number; Properties; Qty Price; Footprint; Texas Instruments; TPS61175PWPR; Switcher; R-PDSO-G14 61 mm²; 0.50 Output Current (A); Duty Cycle; Duty Cycle(%); Cin IRMS(A); IC Ipk; IC Ipk(A)

IC Tj(degC)

Vin= 4.75V Vin= 5.0V Vin= 5.25V
Cin IRMS

Copyright © 2016, Texas Instruments Incorporated; ti.com/webench; 0.50 Output Current (A); D1 Tj(degC); Efficiency(%); Vout Actual(V); Vout p- p(V); M Iavg; M Iavg(A)

Vin= 4.75V Vin= 5.0V Vin= 5.25V
Efficiency

Vout Actual

Vout p- p

Copyright © 2016, Texas Instruments Incorporated; ti.com/webench; Cin Pd; 0.50 Output Current (A); Cin Pd(W); Cout Pd; Cout Pd(W); M Vds Act(V); M Irms; M Irms(A); Pout; Pout(W); Iin Avg; Iin Avg(A)

Vin= 4.75V Vin= 5.0V Vin= 5.25V
M Vds Act

Copyright © 2016, Texas Instruments Incorporated; ti.com/webench; Total Pd; 0.50 Output Current (A); Total Pd(W); Cout IRMS; Cout IRMS(A); L Ipp; L Ipp(A); Diode Pd(W); Loop Response; Gain Phase + 180; 100,000 Frequency; Gain(dB); Phase + 180(degree); Operating Values; Name; Value; Category; Description; 1. Cin IRMS; Current; Input capacitor RMS ripple current; 2. Cout IRMS; Output capacitor RMS ripple current; 3. IC Ipk; Peak switch current in IC; 4. Iin Avg; Average input current; 5. L Ipp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

Vin= 4.75V Vin= 5.0V Vin= 5.25V

Diode Pd

Copyright © 2016, Texas Instruments Incorporated | 6 | ti.com/webench
# | Name | Value | Category | Description

12. M Vds Act | 150.387 mV | General | Voltage drop across the MosFET
13. Mode | CCM | General | Conduction Mode
14. Pout | 6.0 W | General | Total output power
15. Total BOM | $1.77 | General | Total BOM Cost
16. D1 Tj | 34.947 degC | Op_Point | D1 junction temperature
17. Low Freq Gain | 79.414 dB | Op_Point | Gain at 10Hz
18. Vout Actual | 12.078 V | Op_Point | Vout Actual calculated based on selected voltage divider resistors
19. Vout OP | 12.0 V | Op_Point | Operational Output Voltage
20. Cross Freq | 11.933 kHz | Op_point | Bode plot crossover frequency
21. Duty Cycle | 64.896 % | Op_point | Duty cycle
22. Efficiency | 87.846 % | Op_point | Steady state efficiency
23. Gain Marg | -13.657 dB | Op_point | Bode Plot Gain Margin
24. IC Tj | 53.02 degC | Op_point | IC junction temperature
25. ICThetaJA | 44.5 degC/W | Op_point | IC junction-to-ambient thermal resistance
26. IOUT_OP | 500.0 mA | Op_point | Iout operating point
27. Phase Marg | 63.914 deg | Op_point | Bode Plot Phase Margin
28. VIN_OP | 4.75 V | Op_point | Vin operating point
29. Vout p-p | 38.054 mV | Op_point | Peak-to-peak output ripple voltage
30. Cin Pd | 13.82 µW | Power | Input capacitor power dissipation
31. Cout Pd | 2.028 mW | Power | Output capacitor power dissipation
32. Diode Pd | 197.897 mW | Power | Diode power dissipation
33. IC Pd | 517.293 mW | Power | IC power dissipation
34. L Pd | 111.964 mW | Power | Inductor power dissipation
35. Total Pd | 830.121 mW | Power | Total Power Dissipation
36. Vout Tolerance | 3.472 % | Vout Tolerance based on IC Tolerance (no load) and voltage divider
| | | | resistors if applicable

## Design Inputs

# | Name | Value | Description

1. Iout | 500.0 m | Maximum Output Current
2. VinMax | 5.25 | Maximum input voltage
3. VinMin | 4.75 | Minimum input voltage
4. Vout | 12.0 | Output Voltage
5. base_pn | TPS61175 | Base Product Number
6. source | DC | Input Source Type
7. Ta | 30.0 | Ambient temperature

## Design Assistance
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

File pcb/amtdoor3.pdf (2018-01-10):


License: CERN OHL V1.2 HW for AMT Door 3 Raspberry Pi Header

TH Female Bottom or SMT Female Top Header
SMT: Toby Electronics REF-182665-01/REF-182665-03
TH: Digikey 1528-1385-ND
39 P4dnp-REF-182665-01 DNP

Must use RPi pull ups!

1 | PORT2-1 | 2

1 | RFID_RXD | 2

12V Boost 12V/500mA from 5V source for high voltage IO.

12-24V Control
High-power switch for 12-24V/6A.
Can source power from 12V boost or VAUX.
2.2uF 50V W1 TEST_1P BST_SW_D

Should not be used if 5V buck is also stuffed.

5V Buck Regulator
5V/500mA from 12-24V source for high voltage IO.
Should only be used with the aux input (P6)
D.S. Example 9.3.3.1

Id: 1/1 Title: Wide Operation Buck Boost and Automation pHat (WOBBApHAT) File: amtdoor3.sch Sheet: / Author: Ian Hartwig

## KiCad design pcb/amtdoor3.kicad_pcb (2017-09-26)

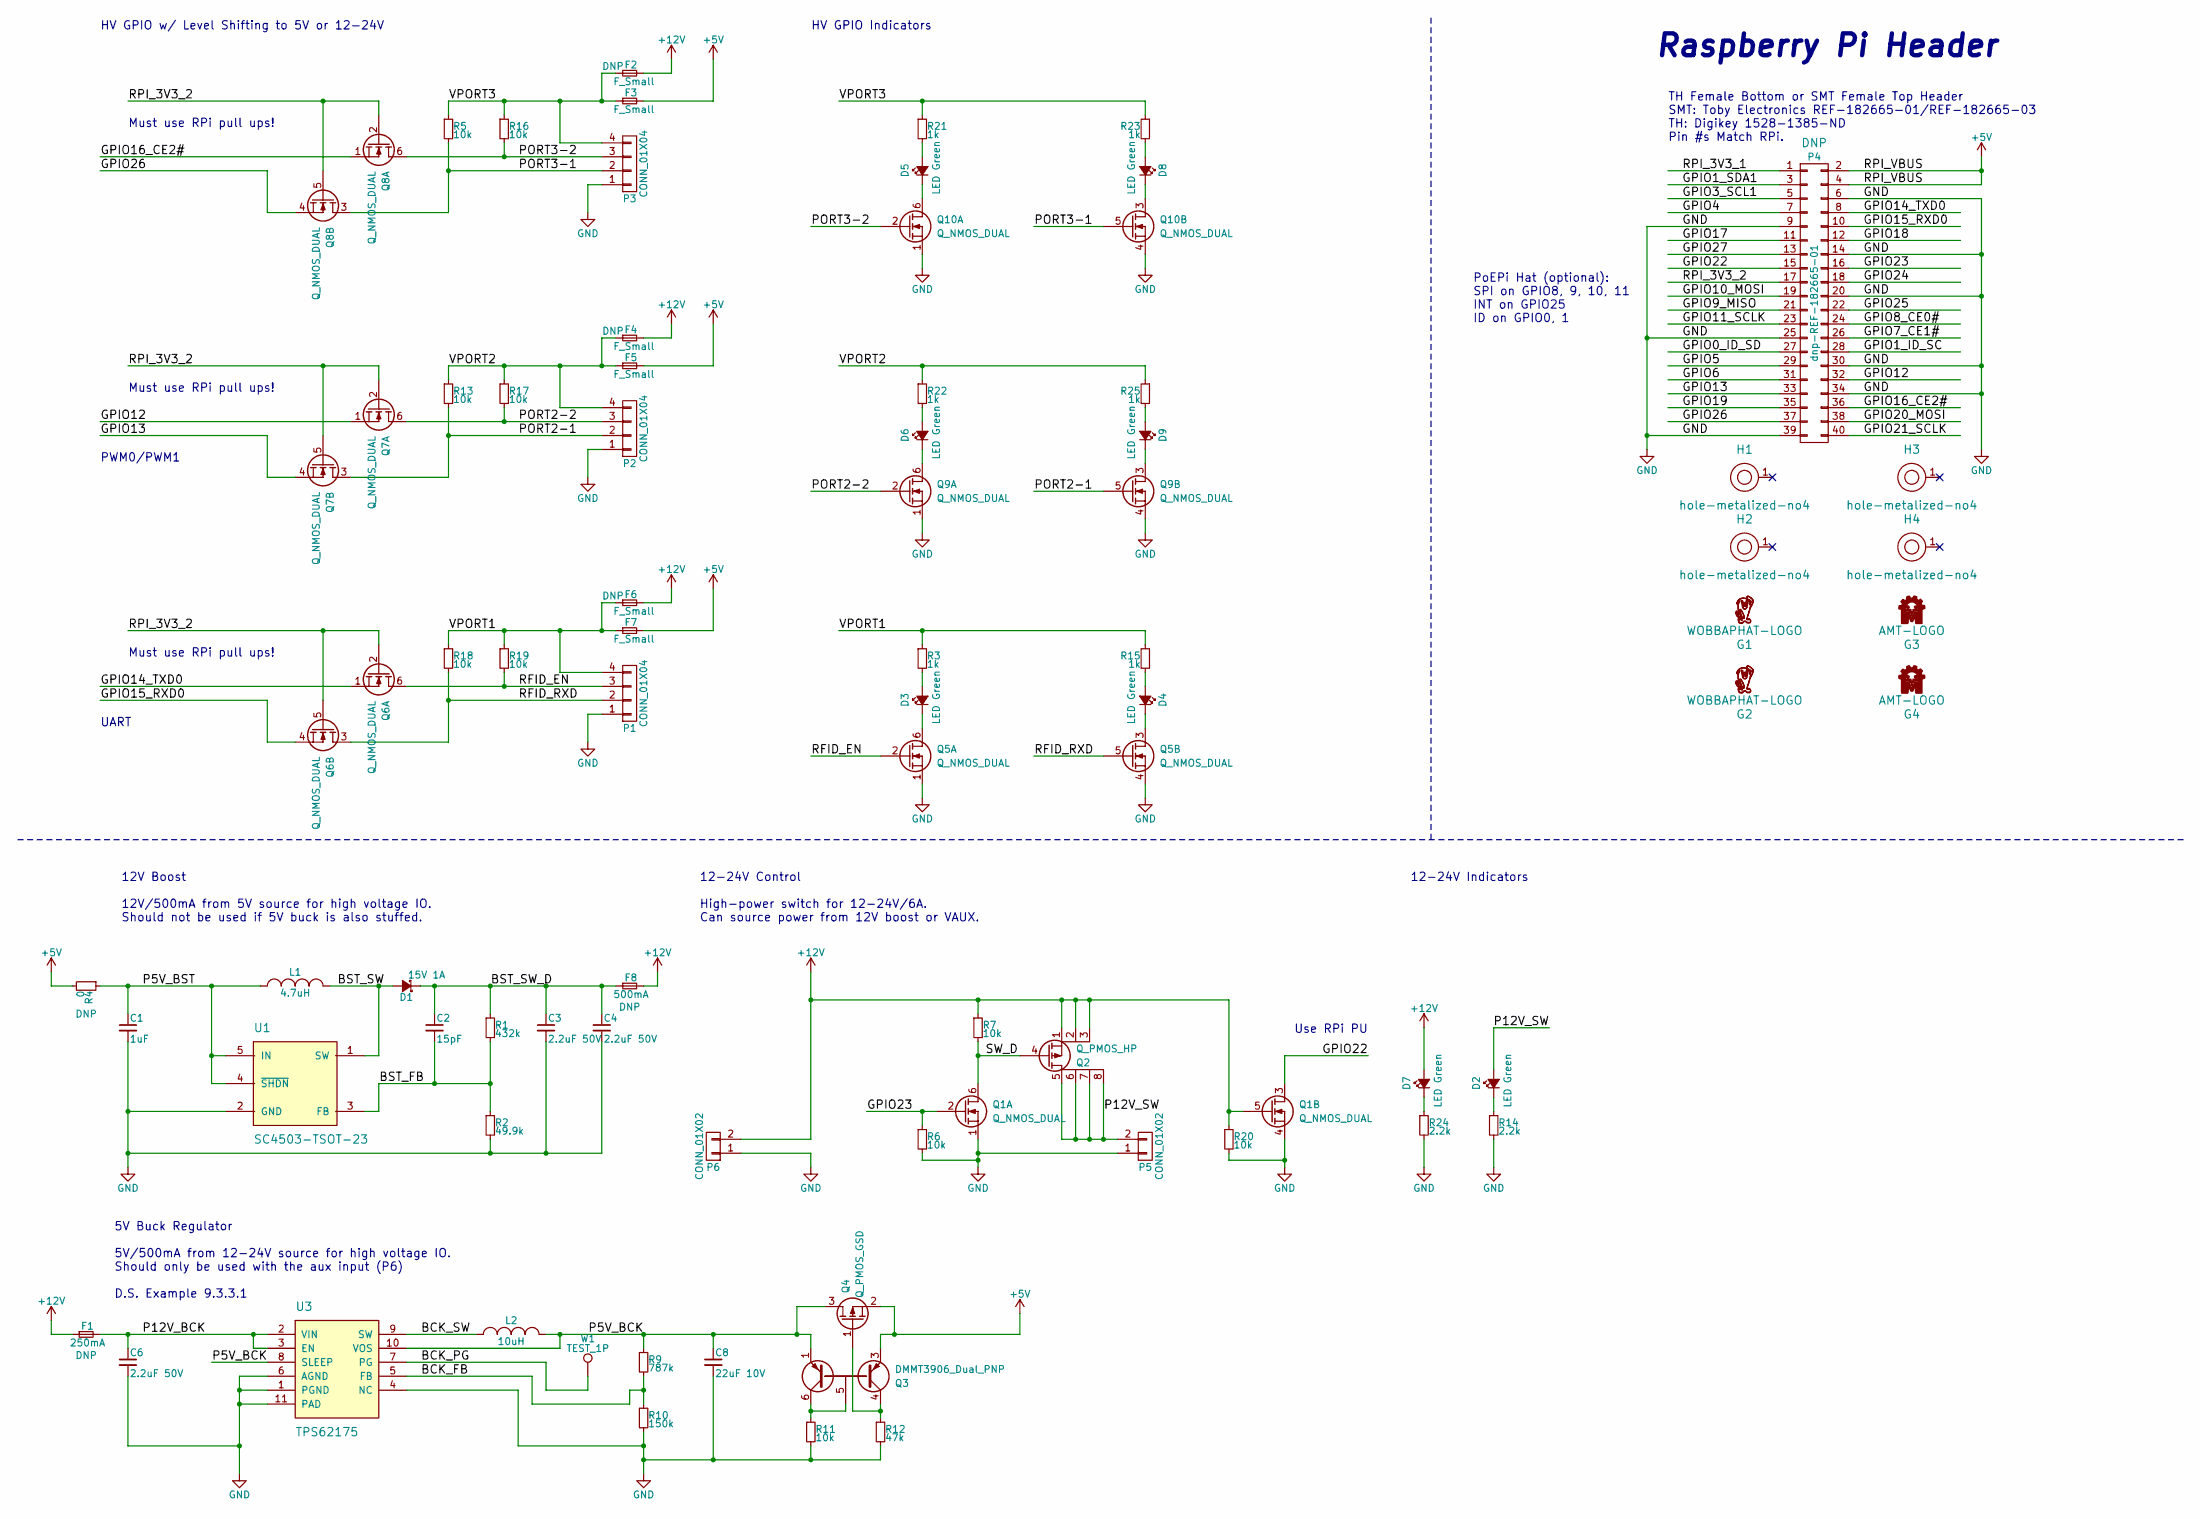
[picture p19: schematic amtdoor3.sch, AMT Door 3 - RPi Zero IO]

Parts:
C1: 1uF; C_0603
C2: 15pF; C_0603
C3, C4, C6: 2.2uF 50V; C_0805
C8: 22uF 10V; C_0805
D1: 15V 1A; SMB_Standard; Mfg Part No VS-10BQ015-M3/5BT; Digikey Part No VS-10BQ015-M3/5BTGICT-ND
D2, D3, D4, D5, D6, D7, D8, D9: LED Green; LED_0603; Mfg Part No LTST-C190GKT; Digikey Part No 160-1183-1-ND
F1: 250mA; R_0805
F2, F3, F4, F5, F6, F7: F_Small; R_0603
F8: 500mA; R_0805
G1: WOBBAPHAT-LOGO; wobbaphat-logo-fcu
G2: WOBBAPHAT-LOGO; wobbaphat-logo-fsilk-lg
G3: AMT-LOGO; amt-logo-fcu
G4: AMT-LOGO; amt-logo-fsilk-lg
H1, H2, H3, H4: hole-metalized-no4; hole-m3
L1: 4.7uH; Choke_SMD_Wuerth-WE-PD2-Typ-L; Mfg Part No NR6028T4R7M; Digikey Part No 587-2100-1-ND
L2: 10uH; Choke_SMD_Wuerth-WE-PD2-Typ-L; Mfg Part No NR6045T100M; Digikey Part No 587-2081-1-ND
P1, P2, P3: CONN_01X04; Socket_Strip_Straight_1x04
P4: dnp-REF-182665-01; Pin_Header_Straight_TH-SMT-NoPaste_2x20
P5, P6: CONN_01X02; Pin_Header_Straight_1x02_Pitch3.5mm; Mfg Part No OSTTE020104; Digikey Part No ED2740-ND
Q1, Q5, Q6, Q7, Q8, Q9, Q10: Q_NMOS_DUAL; SOT-23-6
Q2: Q_PMOS_HP; SOIC-8_3.9x4.9mm_Pitch1.27mm; Mfg Part No DMG4435SSS-13; Digikey Part No DMG4435SSS-13DICT-ND
Q3: DMMT3906_Dual_PNP; SOT-23-6; Mfg Part No DMMT3906-7-F; Digikey Part No DMMT3906-7-FDICT-ND
Q4: Q_PMOS_GSD; SOT-23; Mfg Part No DMP3099L-7; Digikey Part No DMP3099L-7DICT-ND
R1: 432k; R_0603
R2: 49.9k; R_0603
R3, R15, R21, R22, R23, R25: 1k; R_0603
R4: 0; R_0603
R5, R6, R7, R11, R13, R16, R17, R18, R19, R20: 10k; R_0603
R9: 787k; R_0603
R10: 150k; R_0603
R12: 47k; R_0603
R14, R24: 2.2k; R_0603
U1: SC4503-TSOT-23; SOT-23-5; Mfg Part No SC4503TSKTRT; Digikey Part No SC4503TSKCT-ND
U3: TPS62175; DFN-10-1EP_2x3mm_Pitch0.5mm; Mfg Part No todo; Digikey Part No todo
W1: TEST_1P; Measurement_Point_Round-SMD-Pad_Small

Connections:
+5V: F3.2, F5.2, F7.2, P4.2, P4.4, Q3.3 (E2), Q4.2 (S), R4.2
+12V: D7.2 (A), F1.1, F2.2, F4.2, F6.2, F8.2, P6.2, Q1.5 (G), Q2.1 (S), Q2.2 (S), Q2.3 (S), R7.1, R20.1
/BCK_FB: R9.2, R10.1, U3.5 (FB)
/BCK_PG: U3.7 (PG), W1.1
/BCK_SW: L2.1, U3.9 (SW)
/BST_FB: C2.2, R1.2, R2.1, U1.3 (FB)
/BST_SW: D1.2 (A), L1.2, U1.1 (SW)
/BST_SW_D: C2.1, C3.1, C4.1, D1.1 (K), F8.1, R1.1
/GPIO0_ID_SD: P4.27
/GPIO1_ID_SC: P4.28
/GPIO1_SDA1: P4.3
/GPIO3_SCL1: P4.5
/GPIO4: P4.7
/GPIO5: P4.29
/GPIO6: P4.31
/GPIO7_CE1#: P4.26
/GPIO8_CE0#: P4.24
/GPIO9_MISO: P4.21
/GPIO10_MOSI: P4.19
/GPIO11_SCLK: P4.23
/GPIO12: P4.32, Q7.1 (S)
/GPIO13: P4.33, Q7.4 (S)
/GPIO14_TXD0: P4.8, Q6.1 (S)
/GPIO15_RXD0: P4.10, Q6.4 (S)
/GPIO16_CE2#: P4.36, Q8.1 (S)
/GPIO17: P4.11
/GPIO18: P4.12
/GPIO19: P4.35
/GPIO20_MOSI: P4.38
/GPIO21_SCLK: P4.40
/GPIO22: P4.15, Q1.3 (D)
/GPIO23: P4.16, Q1.2 (G), R6.1
/GPIO24: P4.18
/GPIO25: P4.22
/GPIO26: P4.37, Q8.4 (S)
/GPIO27: P4.13
/P5V_BCK: C8.1, L2.2, Q3.1 (E1), Q4.3 (D), R9.1, U3.8 (SLEEP), U3.10 (VOS)
/P5V_BST: C1.1, L1.1, R4.1, U1.4 (~SHDN), U1.5 (IN)
/P12V_BCK: C6.1, F1.2, U3.2 (VIN), U3.3 (EN)
/P12V_SW: D2.2 (A), P5.2, Q2.5 (D), Q2.6 (D), Q2.7 (D), Q2.8 (D)
/PORT2-1: P2.2, Q7.3 (D), Q9.5 (G), R13.2
/PORT2-2: P2.3, Q7.6 (D), Q9.2 (G), R17.2
/PORT3-1: P3.2, Q8.3 (D), Q10.5 (G), R5.2
/PORT3-2: P3.3, Q8.6 (D), Q10.2 (G), R16.2
/RFID_EN: P1.3, Q5.2 (G), Q6.6 (D), R19.2
/RFID_RXD: P1.2, Q5.5 (G), Q6.3 (D), R18.2
/RPI_3V3_1: P4.1
/RPI_3V3_2: P4.17, Q6.2 (G), Q6.5 (G), Q7.2 (G), Q7.5 (G), Q8.2 (G), Q8.5 (G)
/SW_D: Q1.6 (D), Q2.4 (G), R7.2
/VPORT1: F6.1, F7.1, P1.4, R3.1, R15.1, R18.1, R19.1
/VPORT2: F4.1, F5.1, P2.4, R13.1, R17.1, R22.1, R25.1
/VPORT3: F2.1, F3.1, P3.4, R5.1, R16.1, R21.1, R23.1
GND: C1.2, C3.2, C4.2, C6.2, C8.2, P1.1, P2.1, P3.1, P4.6, P4.9, P4.14, P4.20, P4.25, P4.30, P4.34, P4.39, P5.1, P6.1, Q1.1 (S), Q1.4 (S), Q5.1 (S), Q5.4 (S), Q9.1 (S), Q9.4 (S), Q10.1 (S), Q10.4 (S), R2.2, R6.2, R10.2, R11.2, R12.2, R14.2, R20.2, R24.2, U1.2 (GND), U3.1 (PGND), U3.4 (NC), U3.6 (AGND), U3.11 (PAD)
unnamed: D2.1 (K), R14.1
unnamed: D3.1 (K), Q5.6 (D)
unnamed: D3.2 (A), R3.2
unnamed: D4.1 (K), Q5.3 (D)
unnamed: D4.2 (A), R15.2
unnamed: D5.1 (K), Q10.6 (D)
unnamed: D5.2 (A), R21.2
unnamed: D6.1 (K), Q9.6 (D)
unnamed: D6.2 (A), R22.2
unnamed: D7.1 (K), R24.1
unnamed: D8.1 (K), Q10.3 (D)
unnamed: D8.2 (A), R23.2
unnamed: D9.1 (K), Q9.3 (D)
unnamed: D9.2 (A), R25.2
unnamed: Q3.4 (C2), Q4.1 (G), R12.1
unnamed: Q3.5 (B), Q3.6 (C1), R11.1

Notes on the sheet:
Raspberry Pi Header
TH Female Bottom or SMT Female Top Header SMT: Toby Electronics REF-182665-01/REF-182665-03 TH: Digikey 1528-1385-ND Pin #s Match RPi.
HV GPIO w/ Level Shifting to 5V or 12-24V
HV GPIO Indicators
12V Boost 12V/500mA from 5V source for high voltage IO. Should not be used if 5V buck is also stuffed.
5V Buck Regulator 5V/500mA from 12-24V source for high voltage IO. Should only be used with the aux input (P6) D.S. Example 9.3.3.1
12-24V Control High-power switch for 12-24V/6A. Can source power from 12V boost or VAUX.
Must use RPi pull ups!
Use RPi PU
12-24V Indicators
UART
PWM0/PWM1
PoEPi Hat (optional): SPI on GPIO8, 9, 10, 11 INT on GPIO25 ID on GPIO0, 1

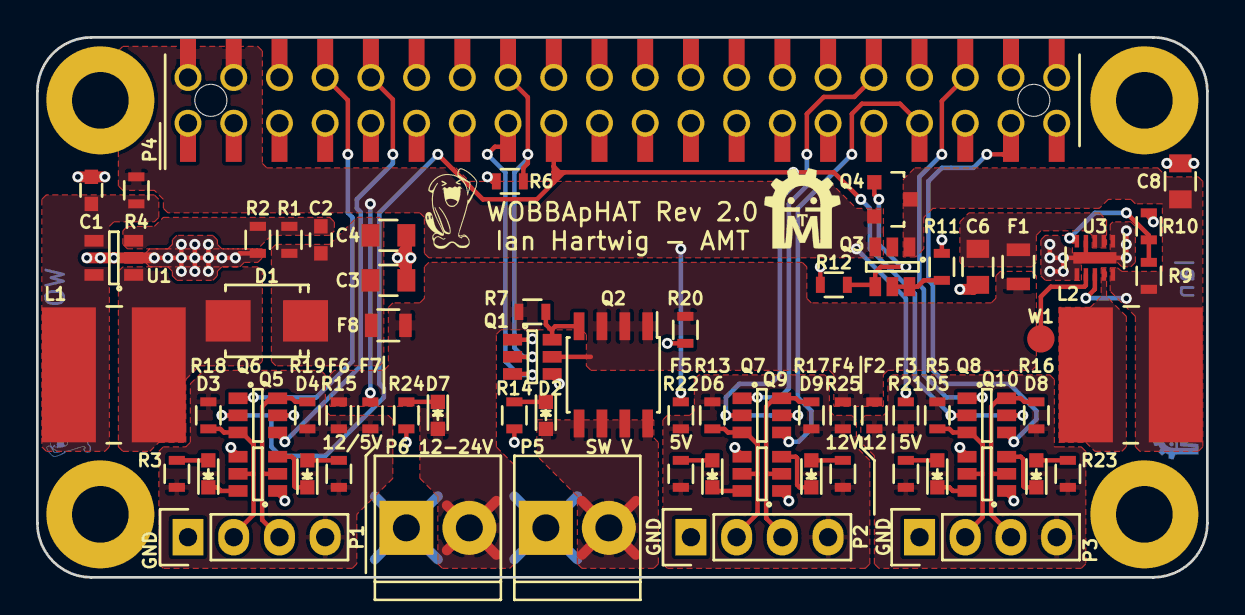
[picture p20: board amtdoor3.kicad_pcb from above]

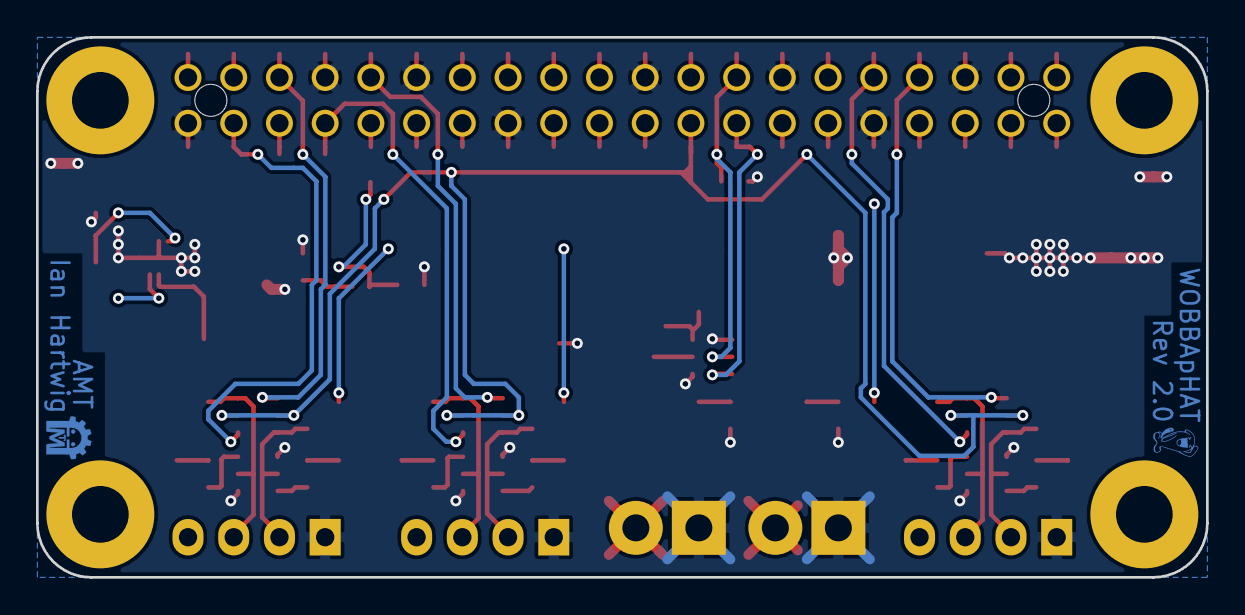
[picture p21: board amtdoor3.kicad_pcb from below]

Board: 2 copper layers, 65.0 x 30.0 mm, 76 parts (2 on the bottom side), 48 nets.

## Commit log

2016-10-23 Add pcb with schematic and layout complete
    [amtdoor3.kicad_pcb, amtdoor3.sch]
2016-10-23 clean up silkscreen, set soldermask expansion, write gerbers
    [amtdoor3-B.Cu.gbl, amtdoor3-B.Mask.gbs, amtdoor3-B.Paste.gbp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]
2017-09-24 new rev schematic updates and footprint grouping
    * change level shifter to NFET gates w/ pull up b/c NVT2002 leaks 5V EN to 3.3V rail
    * add selectable, fused output voltage to each port
    * rename P2 to P4 so the output ports are P1, P2, P3
    * use level shifting on all ports
    * reassign GPIO to ports so we have UART TX+RX, PWM, and plain GPIO
    * add fuses and DNPs so boost and buck can be populated but not interfere
    [amtdoor3.kicad_pcb, amtdoor3.sch]
2017-09-24 new rev layout complete w/ some sch changes to help routing
    * normalize boost net names
    * fix boost part number to TPS62175. TPS62177 is fixed 3.3V
    * DNP one option for output port voltage
    * fix cap + voltage of boost/buck 12/24V decoupling caps C3, C4, C6
    * reassign GPIO to ports to help routing
    [amtdoor3.kicad_pcb, amtdoor3.sch]
2017-09-26 pcb rev 2.0 gerbers, silk logos, routing tweaks
    [amtdoor3-B.Cu.gbl, amtdoor3-B.Mask.gbs, amtdoor3-B.Paste.gbp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]
2018-01-10 update bom info for pcb rev 2.0
    [amtdoor3.csv, amtdoor3.sch]
